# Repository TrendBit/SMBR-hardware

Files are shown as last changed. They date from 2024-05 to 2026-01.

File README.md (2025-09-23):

# SMBR - Hardware
This repository contains the documentation for all hardware modules that make up or can be connected to the Smart Modular BioReactor. All designs were made in KiCAD.

General module specification is to which modules should adhere as much as possible is in [Specification.md](Specification.md)

# General system design
All the main modules are built on a similar basis. These are the RP2040 microcontroller, CANBus and development resources (SWD, UART, etc). The individual modules, in turn, add components to this base that correspond to their specific application. For example, in the case of the Control board, this includes motor drivers or electronics that control and monitor fans. The modules communicate with each other via the CAN bus, where a custom protocol is used.

# Modules
### Interface board
Extension for RPi 4 which adds capabilities for communication and power inputs. Board serves as hub for CAN bus connection to other modules. Modules can be connected via 3 IDC cables or stacking connector on top. Board is connected to RPi via 40 pin connector. Via this connector is Rpi power and communicate with CAN bus transceiver via SPI. I2C can be used to read on board ADC which read board input voltage, current. This board also supplies 5V rail for Rpi and rest of the system. PoE module can be mounted to the board and PoE lines will be passed from RPi header.

<p align="center">
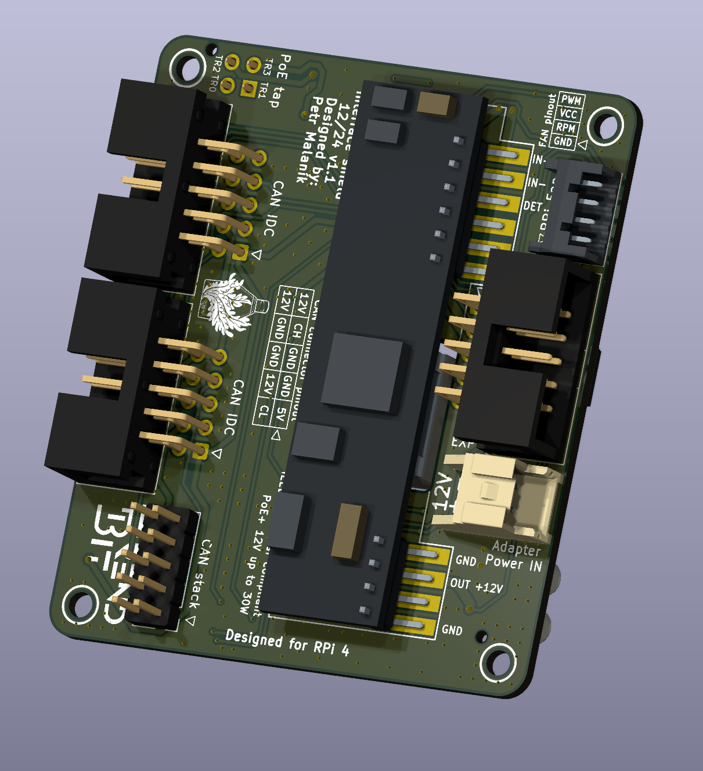
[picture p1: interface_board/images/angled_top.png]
3D Top Angled
  
&nbsp; &nbsp; &nbsp; &nbsp;
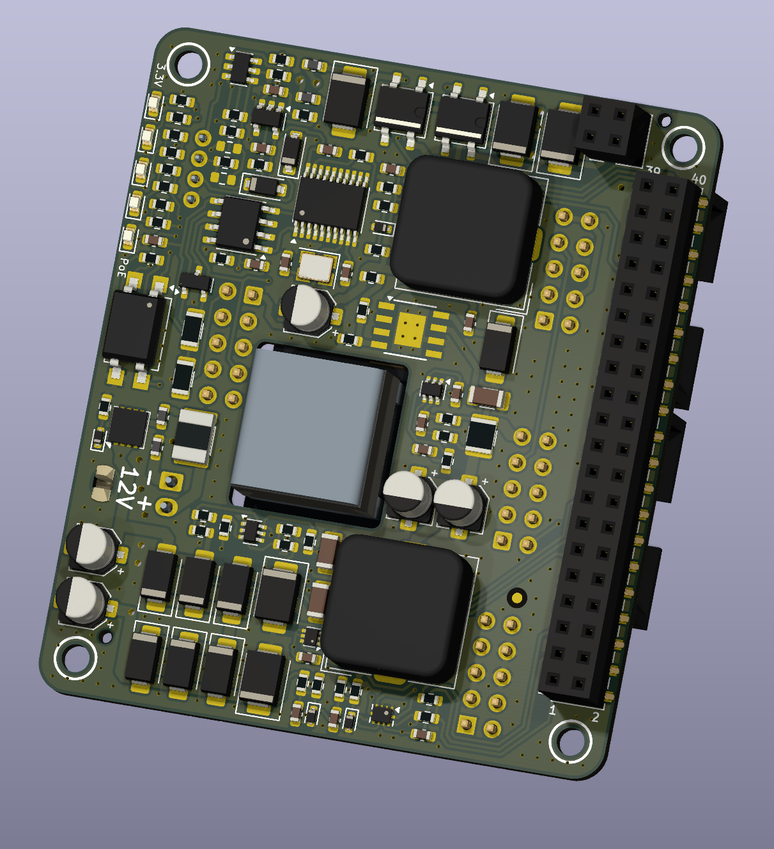
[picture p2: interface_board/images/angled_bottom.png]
3D Bottom Angled
  
</p>

# Control board
Board responsible for main control function of SMPBR. Can be used to control illumination intensity. Drives peltier element which influence temperature of algae in bottle. Controls Aerator, Peristaltic pump, Mixer and heat control fans on device. Reads temperature of heater plate and LED panel. Can be used as additional CAN bus HUB. Is designed to be stacked on top of Interface module, as third layer of sandwich RPi-Interface-Control.

<p align="center">
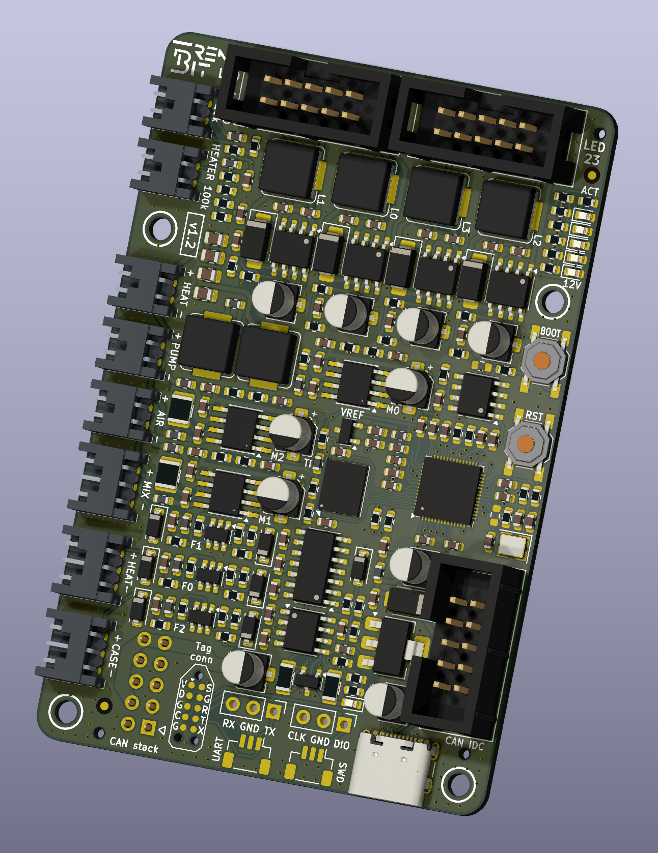
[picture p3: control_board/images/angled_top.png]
3D Top Angled
  
&nbsp; &nbsp; &nbsp; &nbsp;
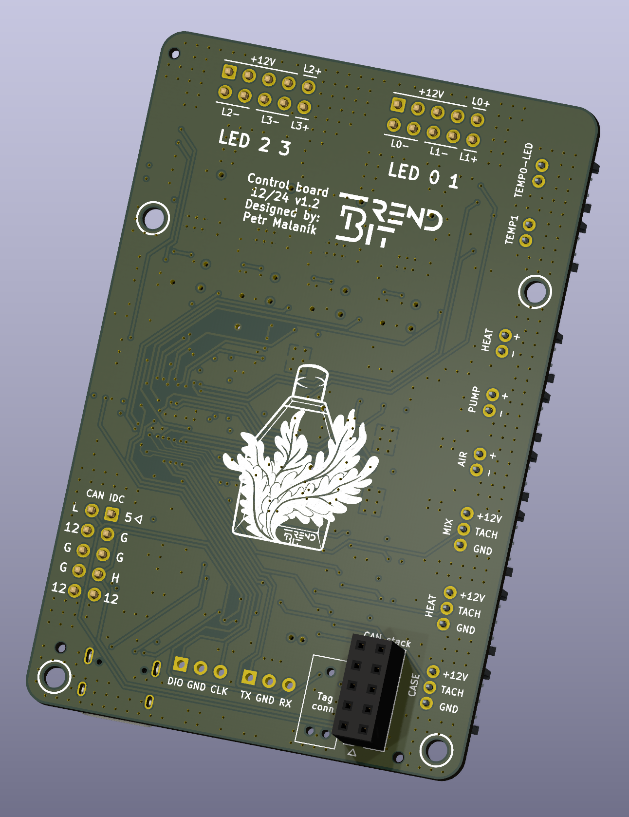
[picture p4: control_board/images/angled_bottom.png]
3D Bottom Angled
  
</p>

### Sensor board
Module performing most of the basic measurements related to experiment. Consists of three boards which  can be connected together around sampling cuvette. Sample is pumped into cuvette and after adaptation the measurements can start. For OJIP measurement sample is saturated with high power 10W Green LED and resulting value is measured with adaptive gain IR energy sensor. Another measurement is optical density which can be measured at 6 defined wavelengths. Board also measures temperature in bottle via two contact-less thermometers (thermopiles).

<p align="center">
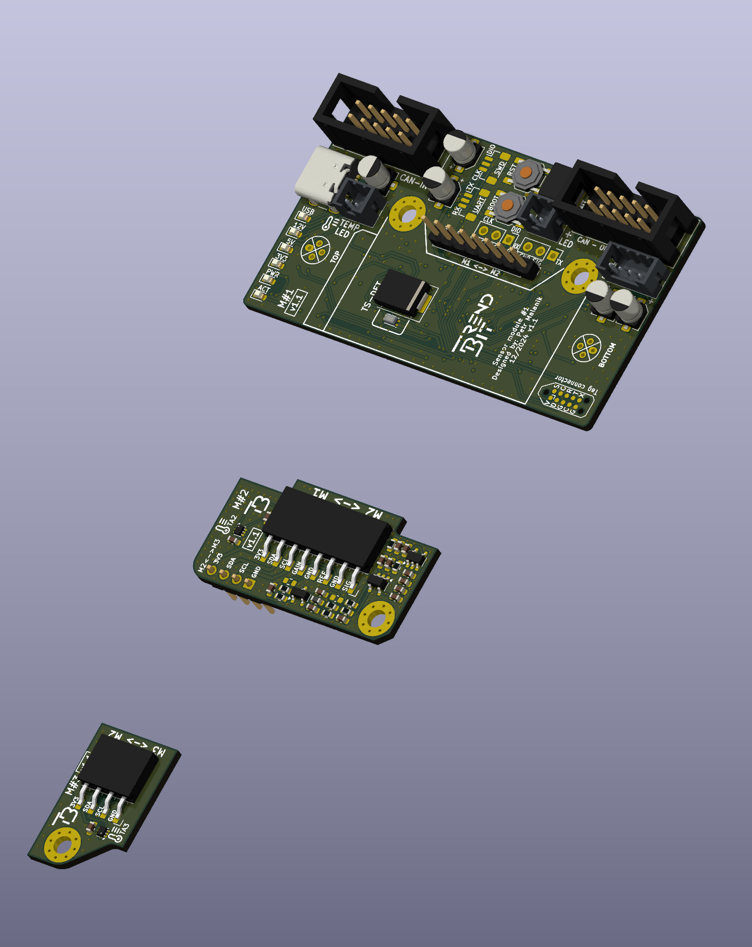
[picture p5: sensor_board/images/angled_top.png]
3D Top Angled
  
&nbsp; &nbsp; &nbsp; &nbsp;
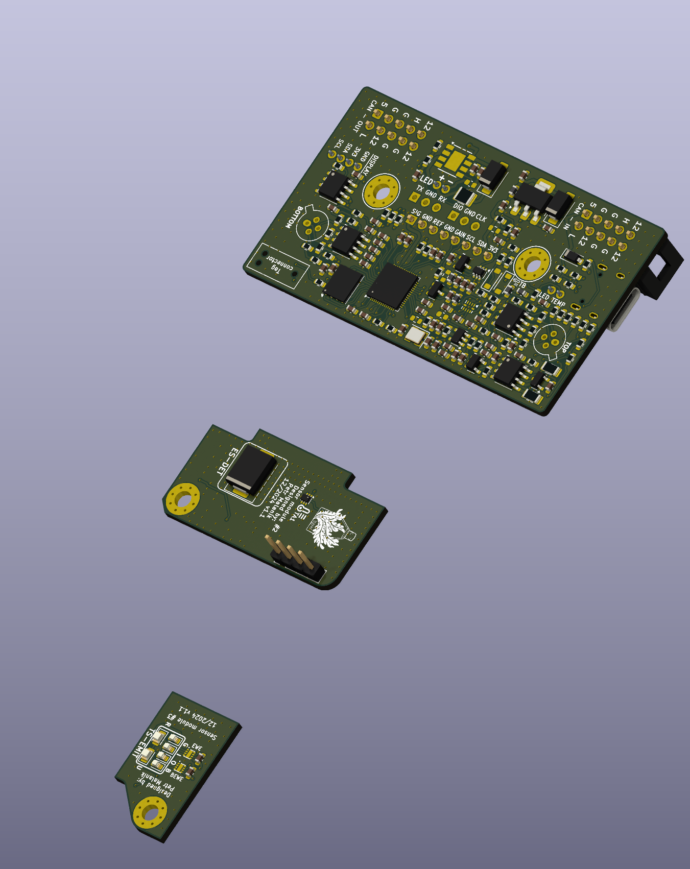
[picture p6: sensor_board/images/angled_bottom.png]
3D Bottom Angled
  
</p>

### Illumination board - Basic RGBW
SMPBR illumination panel with 4 channels. Channels can be controlled individually from control module. Each module has own power limit based on on board sense resistor. Board has integrated thermistor in order to limit heat dissipation which could influence the experiment.

This board has four basic colors:
- Red 625nm 4.8W
- Green 520nm 5.8W
- Blue 465nm 5.8W
- White (Warm) 2700K 6.1W

<p align="center">
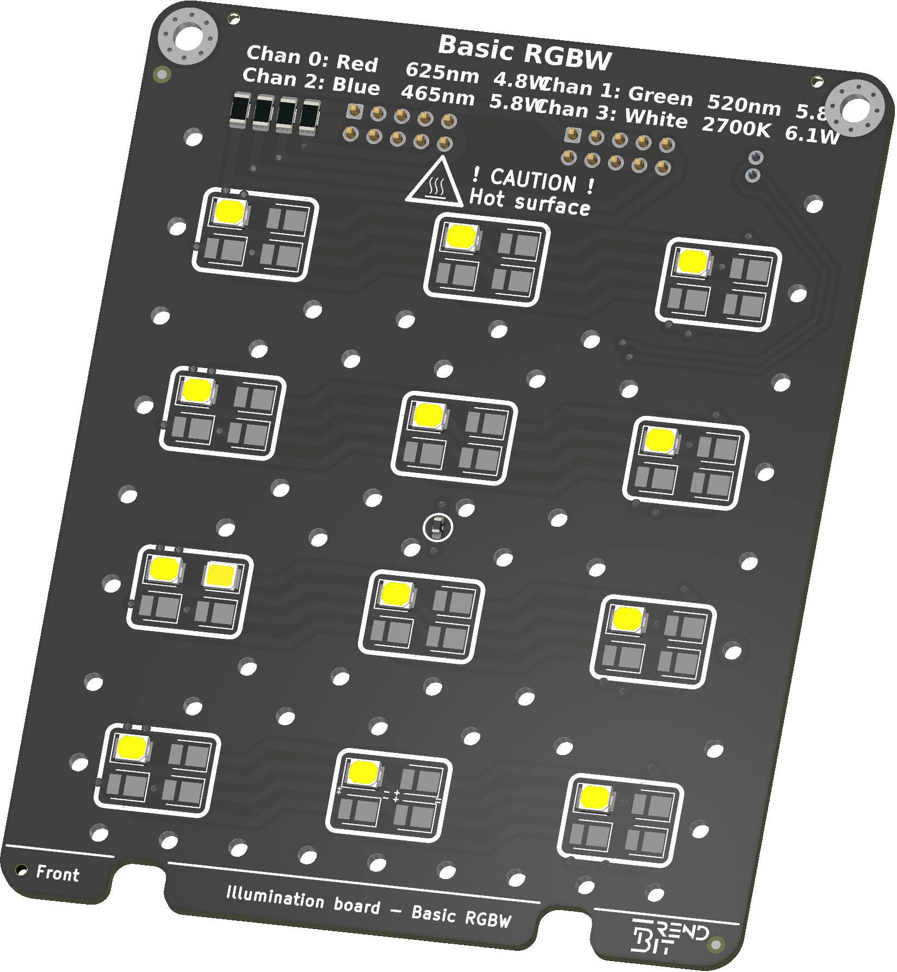
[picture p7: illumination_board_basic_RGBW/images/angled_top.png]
3D Top Angled
  
&nbsp; &nbsp; &nbsp; &nbsp;
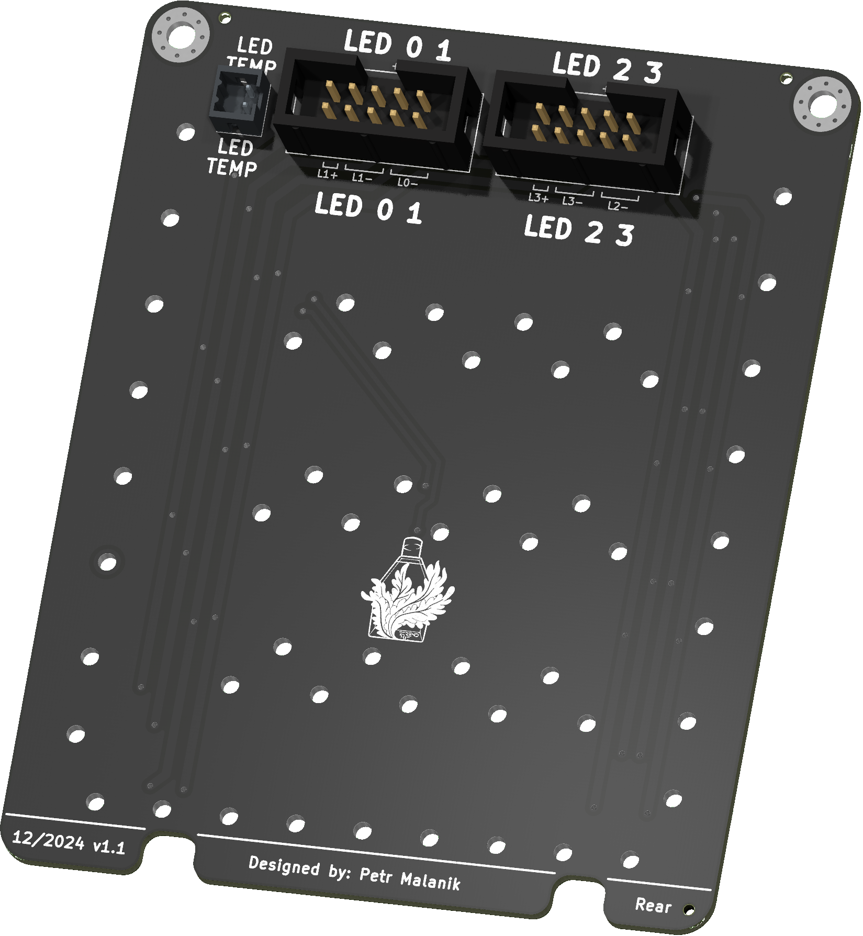
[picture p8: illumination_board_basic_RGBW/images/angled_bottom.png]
3D Bottom Angled
  
</p>

### Motor filter shield for peristaltic pump
Small PCB directly soldered to motor terminals of Peristaltic pump motor. It acts as a low pass filter reducing EMI. However, it can also be soldered directly to the motor chassis, further improving EMC. It simplifies motor connection by allowing the motor to be connected via a connector on the board.
<p align="center">
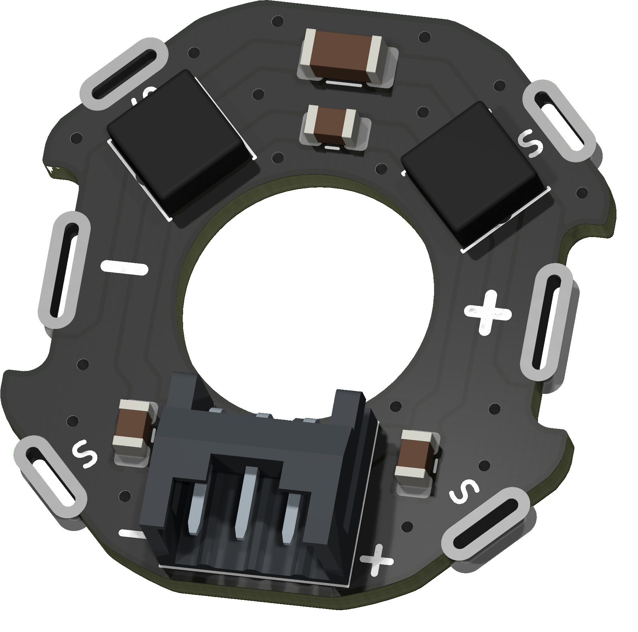
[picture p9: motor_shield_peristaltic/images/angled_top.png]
3D Top Angled
  
&nbsp; &nbsp; &nbsp; &nbsp;
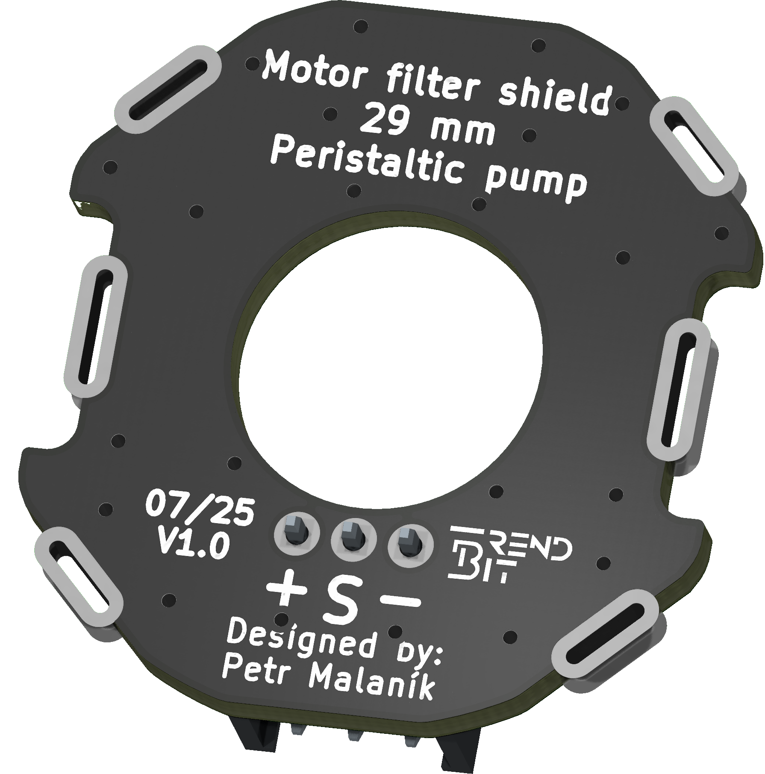
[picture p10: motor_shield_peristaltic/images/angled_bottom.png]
3D Bottom Angled
  
</p>

### Motor filter shield for air pump
Small PCB directly soldered to motor terminals of air pump motor. It acts as a low pass filter reducing EMI. However, it can also be soldered directly to the motor chassis, further improving EMC. It simplifies motor connection by allowing the motor to be connected via a connector on the board.
<p align="center">
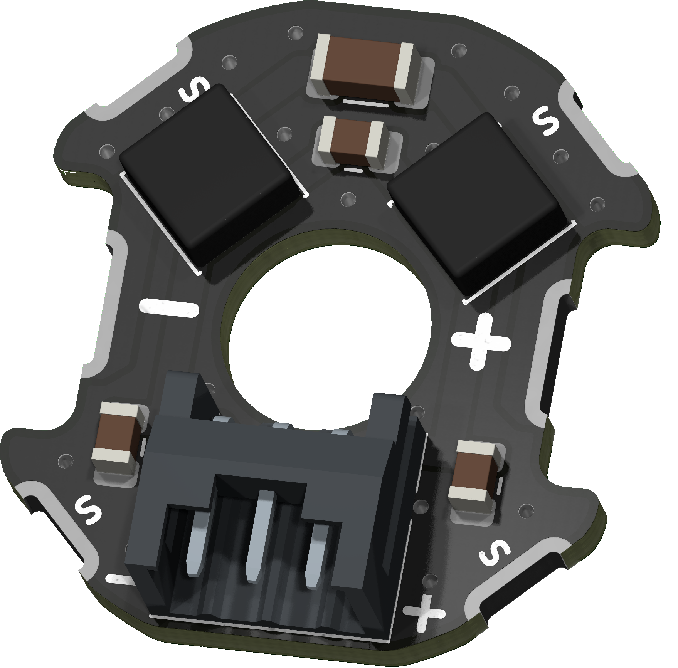
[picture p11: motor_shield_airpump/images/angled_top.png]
3D Top Angled
  
&nbsp; &nbsp; &nbsp; &nbsp;
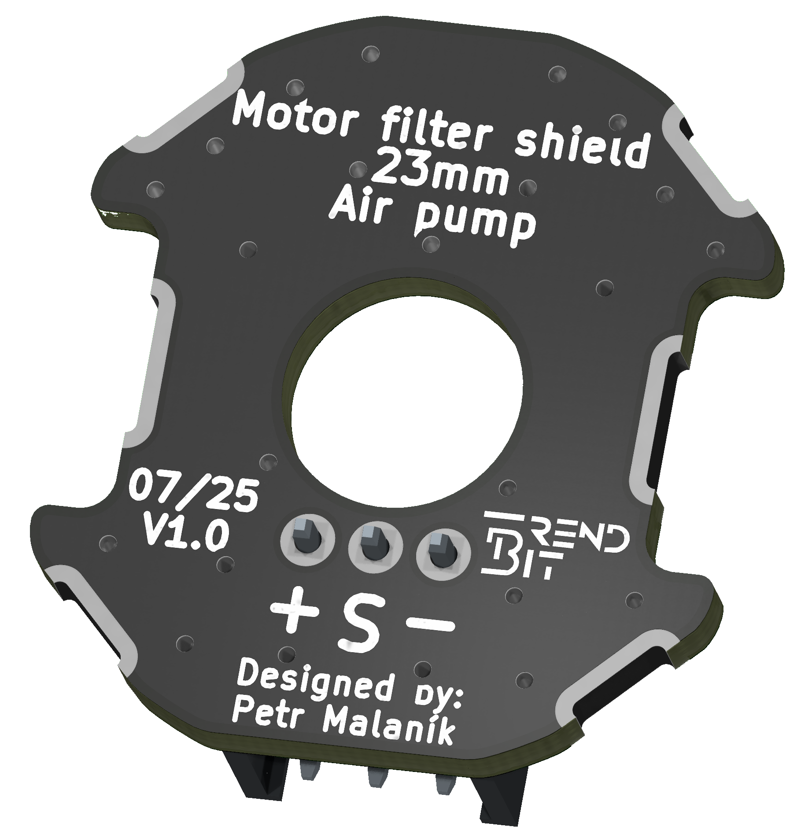
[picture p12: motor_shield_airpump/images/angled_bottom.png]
3D Bottom Angled
  
</p>

### [WIP] Pump board 
Board for expansion pump module, which is used to control additional peristaltic pumps. To this board up to 4 peristaltic pumps can be connected a controlled. Module can be connected to SMPBR reactor via expansion port. Multiple of those modules can be connected to one bio-reactor and can be chained bia expansion ports. Module also have external power, because when more modules will be connected to expansion port, main adapter can be overloaded. External power input is prioritized over power from extension cable.
<p align="center">
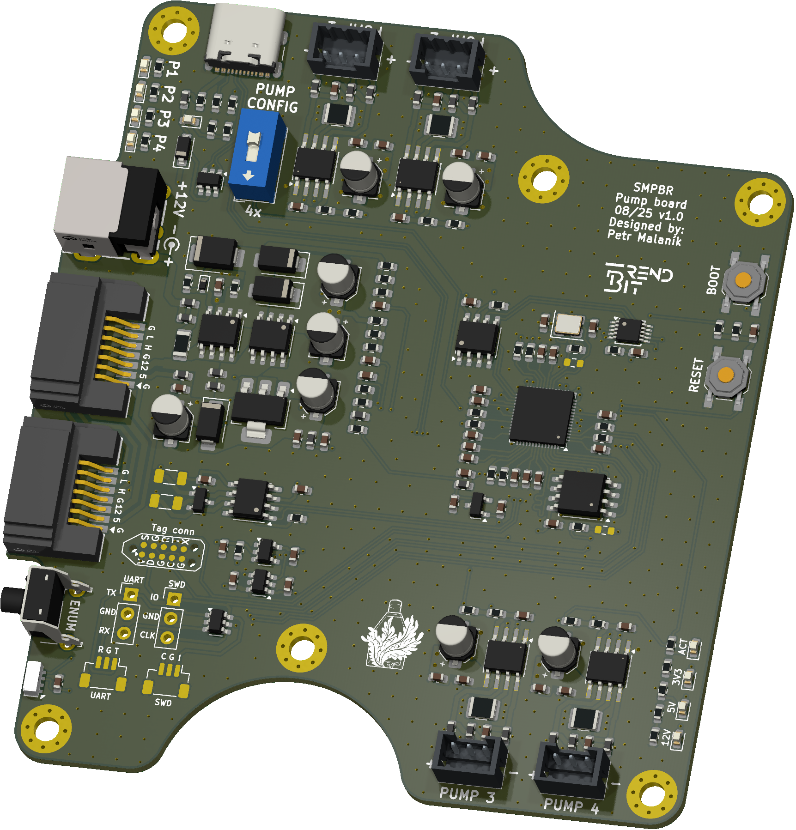
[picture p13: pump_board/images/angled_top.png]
3D Top Angled
  
&nbsp; &nbsp; &nbsp; &nbsp;
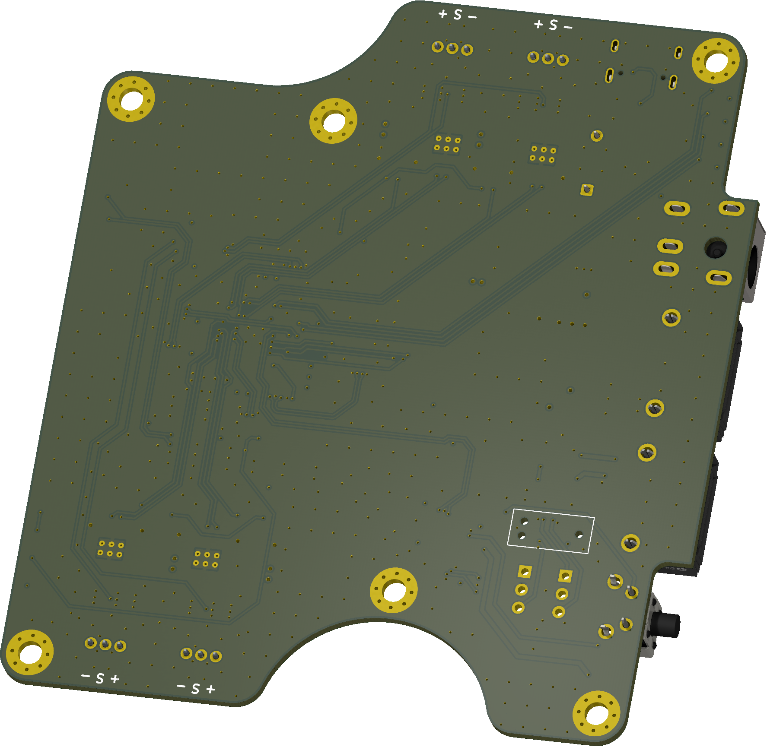
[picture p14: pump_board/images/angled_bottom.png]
3D Bottom Angled
  
</p>

### Sata Expansion port

### Fluorometer LED

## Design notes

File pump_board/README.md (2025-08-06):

# Pump board
Board for expansion pump module, which is used to control additional peristaltic pumps. To this board up to 4 peristaltic pumps can be connected a controlled. Module can be connected to SMPBR reactor via expansion port. Multiple of those modules can be connected to one bio-reactor and can be chained bia expansion ports. Module also have external power, because when more modules will be connected to expansion port, main adapter can be overloaded. External power input is prioritized over power from extension cable.

<p align="center">
  3D Top Angled
&nbsp; &nbsp; &nbsp; &nbsp;
  3D Bottom Angled
</p>

## Manufacturing configuration
- Single pieces
- Thickness: 1.6mm
- Layers: 4
- Color: Green/White
- Surface: HASL Lead Free
- Confirm Production file: No
- Mark: Remove
- Assembly: Standard - Top Side
- Edge Rails/Fiducials: Added by JLCPCB
- Confirm parts placement: Yes

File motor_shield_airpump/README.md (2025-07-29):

### Motor filter shield for air pump
Small PCB directly soldered to motor terminals of air pump motor. It acts as a low pass filter reducing EMI. However, it can also be soldered directly to the motor chassis, further improving EMC. It simplifies motor connection by allowing the motor to be connected via a connector on the board.

<p align="center">
  3D Top Angled
&nbsp; &nbsp; &nbsp; &nbsp;
  3D Bottom Angled
</p>

## Manufacturing configuration
- Panel by customer, 3x3
- Thickness: 1.6mm
- Color: Black/White
- Surface: HASL Lead Free
- Confirm Production file: Yes
- Mark: Remove
- Assembly: Standard - Both sides
- Castelated holes: Yes (2 sides)
- Assembly: Standard - Top Side
- Edge Rails/Fiducials: Added by customer
- Confirm parts placement: Yes

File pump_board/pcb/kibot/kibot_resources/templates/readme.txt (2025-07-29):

<p align="center" width="100%">
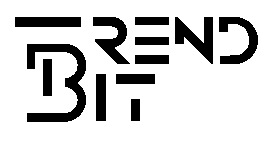
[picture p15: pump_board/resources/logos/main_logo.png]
  
</p>

<h1 align="center">${PROJECT_NAME} / ${BOARD_NAME}</h1>

<p align="center">
  3D Top Angled
&nbsp; &nbsp; &nbsp; &nbsp;
  3D Bottom Angled
</p>

***

## SPECIFICATIONS

| Parameter | Value | 
| --- | --- |
| Dimensions | ${bb_w_mm} × ${bb_h_mm} mm |

***

## DIRECTORY STRUCTURE

    .
    ├─ Computations       # Misc calculations
    ├─ HTML               # HTML files for generated webpage
    ├─ Images             # Pictures and renders
    │
    ├─ kibot_resources    # External resources for KiBot
    │  ├─ colors          # Color theme for KiCad
    │  ├─ fonts           # Fonts used in the project
    │  ├─ scripts         # External scripts used with KiBot
    │  └─ templates       # Templates for KiBot generated reports
    │
    ├─ kibot_yaml         # KiBot YAML config files
    ├─ KiRI               # KiRI (PCB diff viewer) files
    │
    ├─ lib                # KiCad footprint and symbol libraries
    │  ├─ 3d_models       # Component 3D models
    │  ├─ lib_fp          # Footprint libraries
    │  └─ lib_sym         # Symbol libraries
    │
    ├─ Logos              # Logos
    │
    ├─ Manufacturing      # Assembly and fabrication documents
    │  ├─ Assembly        # Assembly documents (BoM, pos, notes)
    │  │
    │  └─ Fabrication     # Fabrication documents (ZIP, notes)
    │     ├─ Drill Tables # CSV drill tables
    │     └─ Gerbers      # Gerbers
    │
    ├─ Report             # Reports for ERC/DRC
    ├─ Schematic          # PDF of schematic
    ├─ Templates          # Title block templates
    ├─ Testing
    │  └─ Testpoints      # Testpoints tables      
    │
    └─ Variants           # Outputs for assembly variants

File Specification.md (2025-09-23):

# General specification for SMBR modules
This specification describes the characteristics of modules that should be adhered to under ideal conditions when developing new modules. The purpose is to ensure maximum consistency between modules and thus increase the compatibility of firmware modules and components. However, this should not be at the expense of reduced functionality or user discomfort. 

## MCU
For maximum FW compatibility (modules, components, libraries), the RP2040 microcontroller from the RaspberryPi Foundation should be used. Alternatively, if it is not suitable, then the RP2354 or other future models can be used, provided they are compatible with the FW base. The advantage of using the same MCU is, for example, that identical code can be used for CAN bus content, message routing, and administrative message processing, regardless of which module it is located on. The standard MCU speed is 200 MHz with a 12 MHz crystal.

#### CAN Bus
The bus interface is ideally connected to the GPIO_4(TX) and GPIO_5(RX) pins of the MCU. The converter is capable of reaching speeds of 1 Mbit/s (e.g., SN65HVD230 in HighSpeed mode), but the actual speed used is 500 kB/s. Overvoltage protection on bus lines. Termination should be on the furthest module, but due to potentially strong interference, it is primarily expected on the Sensor module. If termination is installed on other modules by default, it should be disconnectable using a switch/jumper/pin header. The second termination is permanently installed on the Interface module.

#### Flash Memory
Externally connected QSPI Flash memory for the MCU program. It should not be used for storing persistent data (calibration) but for the program (main and bootloader). Minimum size 16 MBit(MB). To store application data, the module should contain some additional memory, such as I2C EEPROM. 

EEPROM is used as standard memory and connected to I2C1 on pins GPIO18/19 with address 0x50 (7-bit). It is used to store information about the module and its instance.

## Interfaces
Standard interfaces used for communication with the board. CAN bus is the only application interface; the others are used for development and debugging.

#### USB-Type C
Port enabling data transfer via USB FS with UBS Type-C connector. It is connected to the MCU's USB_Dx pins. It must contain CC pull-down resistors (2x 5.1k) and should enable power supply to the device via USB so that the module's firmware can be updated.

It allows you to upload a CAN bootloader (catapult) or standard application firmware for testing using a USB bootloader. It can also be used to connect to the module's CLI interface, which contains information about when the system was built and can provide additional development tools.

#### UART + SWD
Development interface enabling FW stepping with the help of a connected debug probe. The use of an RPi Debug probe is primarily assumed, which corresponds to the pinout of the connectors. The FW logger output is connected to the serial port, but the logger must be enabled in the FW configuration and set to a sufficient level. The serial port speed is 921600 baud.

#### CAN connector
Connector for CAN BUS application interface. It can exist in multiple form factors, but two are most common are 10-pin IDC connector for internal connections within the device and external SATA connector (7-pin).

#### Tag connector
The tag connector is an alternative programming connector that allows you to work with the board when connected via pogo pins (available as a special counterpart). It contains SWD and a serial link. Its primary use is for quick connection to the board for the purpose of changing the firmware.

#### Version resistors
A divider consisting of two resistors that defines the HW version of its output voltage. The resistor values for each version should be identical between modules. The divider is connected to the ADC0 input of the RP2040 MCU.

Values (1% precision):
| Version | R_V1 | R_V2 | Voltage |
|---|---|---|---|
| X.0 |  1k  |  10k |  3.00 V |
| X.1 |  10k |  1k  |  0.30 V |
| X.2 |  10k | 5.1k |  1.11 V |
| X.3 | 5.1k |  10k |  2.18 V |
| X.4 | 5.1k |  1k  |  0.54 V |
| X.5 |  1k  | 5.1k |  2.76 V |

Reserved values:
0V, 3.3V, 1.65V

#### Buttons
Buttons for basic control of the board. These are the reset and boot buttons. The reset button is connected to the MCU RUN pin. Pressing it resets the MCU, pressing it twice in quick succession starts the built-in CAN bootloader and pauses the boot process so that the FW can be uploaded via CAN. However, the CAN bootloader must already be uploaded to the system in some way (it can also be together with the application FW). Holding down the BOOT button during startup or reset activates the USB bootloader, allowing you to upload the CAN bootloader, application firmware, or both. The BOOT button is connected to the CS pin of the Flash memory.

#### LEDs
Each module should contain at least one primary diagnostic LED (LED1) indicating the status of the device. This LED should be visible to the user without major modifications to the device. The preferred color of this signal LED is green, and it should be on pin GPIO24 of the RP2040 MCU. This LED is configurable for each module, so it can be set using FW. However, it is also used by the bootloader (Katapult) and should therefore be on the same pin on all devices, as this allows the same bootloader firmware to be used on all boards. The function of this LED is defined by an abstract class from which all modules are derived, and its behavior is therefore the same for all modules. During bootloader operation, it flashes slowly (1 Hz) and indicates the firmware flashing process. During application operation, it flashes quickly (2.5 Hz) and stops flashing in the event of a critical error.

It is recommended to connect the secondary LED (LED2) to GPIO25 MCU, and it should be yellow. The function of this LED is not defined, but it should indicate ongoing processes related to a specific function of the model (for example, OJIP measurement on the sensor module).

Additional red LEDs should ideally indicate active power branches. This can be used to detect power supply problems, for example, in external modules that may be powered by a hybrid power supply.

#### Enumeration interface
Button and indicator LED designed for modules that allow multiple instances in the system, such as the pump module. Pressing the button sets the instance, which is then indicated by the color of the LED. The button is normally connected to GPIO22. An RGB LED is used as the LED and can be controlled arbitrarily, but it is recommended to use a single-pin addressing protocol (such as WS2818) on GPIO23.

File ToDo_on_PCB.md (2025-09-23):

# Pump board v 1.1
- [ ] Fix incorrect type of Barrel jack connector

# Fluoro LED board v1.3
- [ ] Change PCB from aluminum backed to normal FR4 with heat vias
    - In this case connectors can be used
- [ ] Use one 4-pin connector for  to reduce number of wires

# Sensor board v1.2
- [ ] Add protection resistors to SWD connector (100R) based on pico-probe
- [ ] Connect Fluorometer LED with 3 or 4 wire cable

# Control board v1.3
- [ ] Add protection resistors to SWD connector (100R) based on pico-probe
- [ ] Reduce input current limitation on FAN control MOSFETs
    - Those resistors limits how fast can FAN MOSFET close and open
- [ ] Mark CAN bus resistors as DNP (those should be placed on Sensor module)
    - Or make them possible to enable by resistor

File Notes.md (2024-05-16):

# RPI - Can bus  

 - Add overlay to load during boot to `/boot/firmware/config.txt`  
```  
dtparam=spi=on  
dtoverlay=mcp2515-can0,oscillator=12000000,interrupt=25,spimaxfrequency=2000000  
```  
- Install tool: `sudo apt-get install can-utils`  
- Setup interface: `sudo ip link set can0 up type can bitrate 1000000`  
- Persistently configure interface in file `/etc/network/interfaces`
```
auto can0
iface can0 can static
        bitrate 1000000
```

## Test  
CAN interface can be setup in loopback mode.  
```  
sudo ip link set can0 down  
sudo ip link set can0 type can bitrate 1000000 loopback on  
sudo ip link set can0 up type can bitrate 1000000  
```  
In two terminals run this commands:  
Term #1 - `candump can0`  
Term #2 - `cansend can0  000#11.22.33.44`  

Result should be two lines (one for send, one for receive via loopback):
```
  can0  000   [4]  11 22 33 44
  can0  000   [4]  11 22 33 44
```
If interface is not setup as loopback no data will be visible in `candump` because frame was not ACKed.

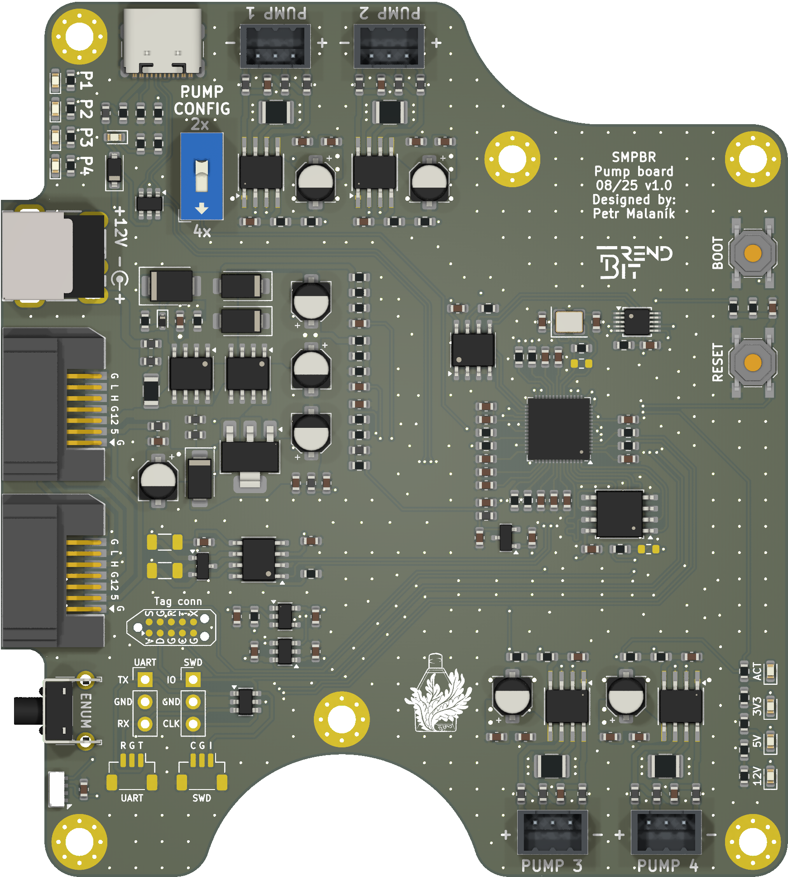
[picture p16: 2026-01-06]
pump_board/images/top.png

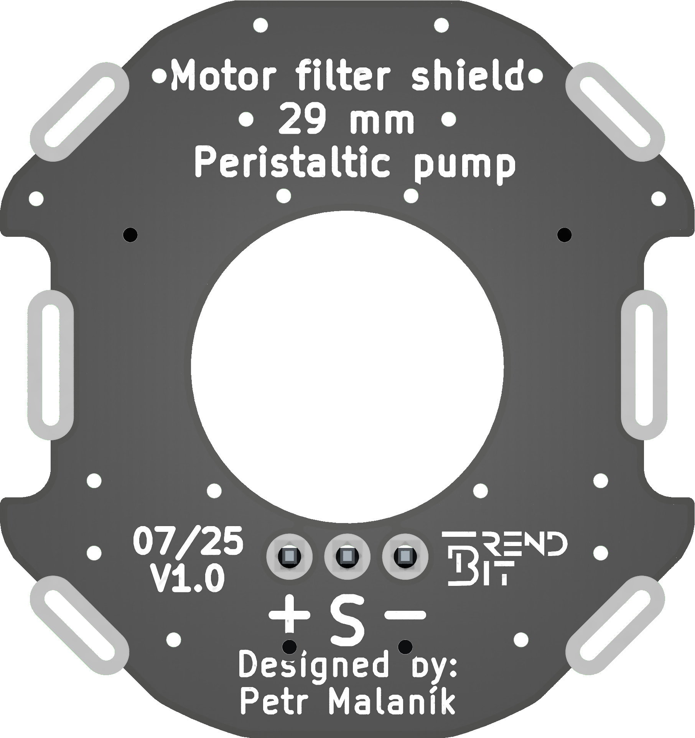
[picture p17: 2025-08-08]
motor_shield_peristaltic/images/bottom.png

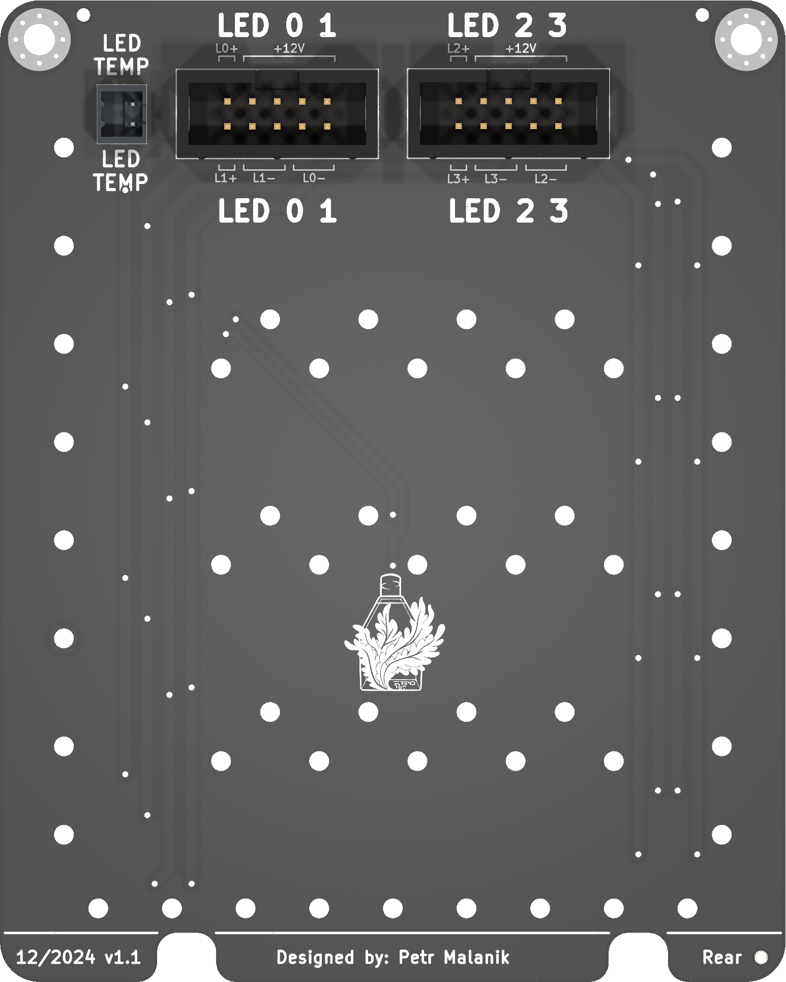
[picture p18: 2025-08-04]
illumination_board_basic_RGBW/images/bottom.png

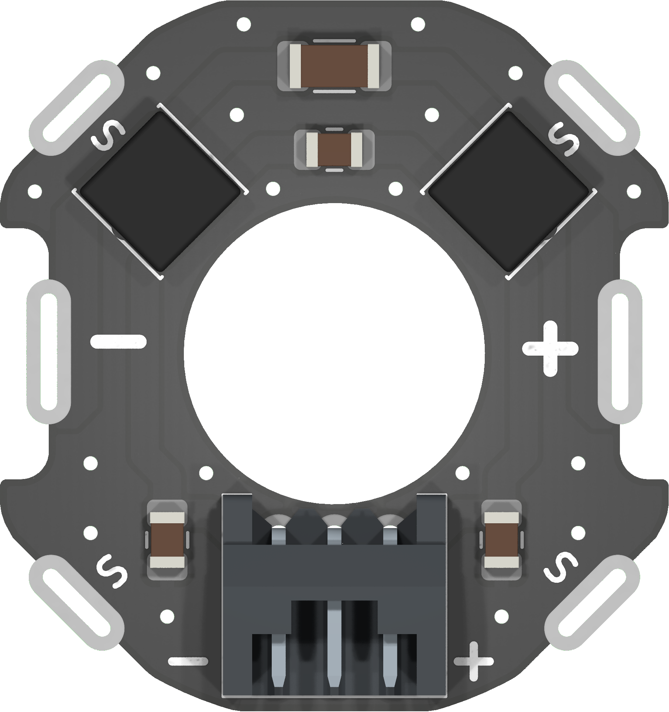
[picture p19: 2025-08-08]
motor_shield_peristaltic/images/top.png

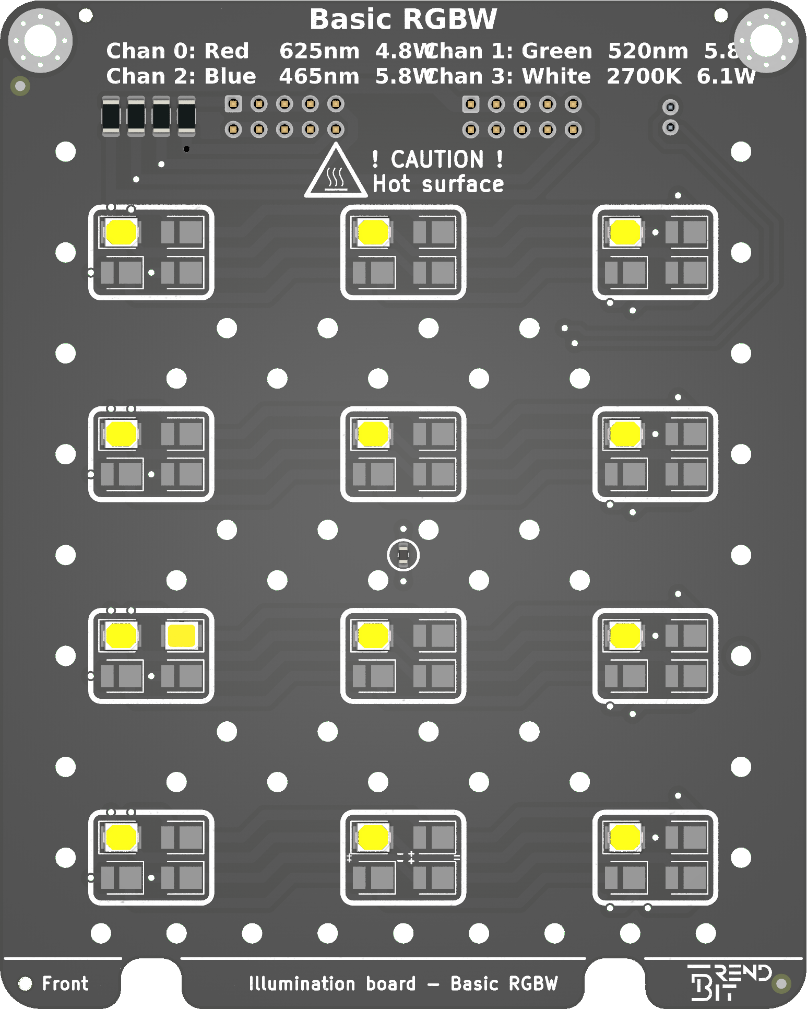
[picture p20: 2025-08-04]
illumination_board_basic_RGBW/images/top.png

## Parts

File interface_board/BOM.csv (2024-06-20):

Reference | Value | Package | Quantity | MPN | LCSC
C2,C4,C10,C11,C15 | 10nF | Capacitor_SMD:C_0603_1608Metric | 5 |  | C57112
C8,C9 | 10pF | Capacitor_SMD:C_0603_1608Metric | 2 |  | C1634
C12,C13,C14,C18,C19,C23 | 100nF | Capacitor_SMD:C_0603_1608Metric | 6 |  | C14663
C5,C6,C16 | 10uF/50V | Capacitor_SMD:C_1206_3216Metric | 3 |  | C13585
C1,C3,C7,C17,C20,C21,C22 | 10uF/25V | Capacitor_SMD:CP_Elec_4x5.4 | 7 | CK1E100M-CRC54 | C3001226
J4,J5,J6 | HC-JN254-2-05-W | Connector_IDC:IDC-Header_2x05_P2.54mm_Horizontal | 3 | HC-JN254-2-05-W | C5372873
J2 | PH-00244 | Connector_PinHeader_2.54mm:PinHeader_2x05_P2.54mm_Vertical | 1 | PH-00244 | C2829881
J3 | FH-00221 | Connector_PinSocket_2.54mm:PinSocket_2x02_P2.54mm_Vertical | 1 | FH-00221 | C2685206
P1 | PM254-2-20-S-8.5 | Connector_PinSocket_2.54mm:PinSocket_2x20_P2.54mm_Vertical_SMD | 1 | PM254-2-20-S-8.5 | C3975165
Y2 | 12MHz | Crystal:Crystal_SMD_Abracon_ABM8G-4Pin_3.2x2.5mm | 1 | ABM8G-12.000MHZ-4Y-T3 | C2933034
D12,D13,D14,D15,D20,D21 | CDBA340 | Diode_SMD:D_SMA | 6 | CDBA340-HF | C8678
D1,D2,D5 | SMBJ58CA | Diode_SMD:D_SMB | 3 | SMBJ58CA | C19077592
D6,D9 | SMBJ13CA | Diode_SMD:D_SMB | 2 | SMBJ13CA | C19077568
D7,D10,D22 | MM5Z5V1 | Diode_SMD:D_SOD-523 | 3 | MM5Z5V1 | C2904385
D8 | BZT52C8V2 | Diode_SMD:D_SOD-523 | 1 | BZT52C8V2 | C19077465
D3,D4 | ABS20M | Diode_SMD:Diode_Bridge_Diotec_ABS | 2 | MB24S | C2903933
F1 | 3A | Fuse:Fuse_1812_4532Metric | 1 | 1812L300/24SLER | C5301865
FB1,FB2,FB3,FB4 | 10R@100MHz | Inductor_SMD:L_0603_1608Metric | 4 | GZ1608D601TF | C2971881
L1,L2 | 22uH/3A | Inductor_SMD:L_TDK_SLF12565 | 2 | FHC1365-220M | C2761928
D11,D16,D17,D18,D19 | RED | LED_SMD:LED_0603_1608Metric | 5 | KT-0603R | C2286
U4 | TLA2024 | Package_DFN_QFN:Texas_UQFN-10_1.5x2mm_P0.5mm | 1 | TLA2024IRUGT | C2876104
U7 | INA213 | Package_DFN_QFN:UQFN-10_1.4x1.8mm_P0.4mm | 1 | INA213AIRSWR | C2870401
U5 | SN65HVD230 | Package_SO:SOIC-8_3.9x4.9mm_P1.27mm | 1 | SN65HVD230DR | C12084
U2 | FOD817S | Package_SO:SSO-4_6.7x5.1mm_P2.54mm_Clearance8mm | 1 | FOD817S | C106900
U6 | TPS5430DDA | Package_SO:TI_SO-PowerPAD-8_ThermalVias | 1 | TPS5430DDAR | C9864
U3 | MCP2515-I/ST | Package_SO:TSSOP-20_4.4x6.5mm_P0.65mm | 1 | MCP2515-I/ST | C185941
Q2,Q3 | SiSA35DN | Package_SO:Vishay_PowerPAK_1212-8_Single | 2 | SISA35DN-T1-GE3 | C177036
D23 | PSM712-LF-T7 | Package_TO_SOT_SMD:SOT-23 | 1 | PSM712-LF-T7 | C32677
Q1,Q4 | DMN63D8LDW | Package_TO_SOT_SMD:SOT-363_SC-70-6 | 2 | DMN63D8LDW-7 | C211422
R1,R3,R5,R6,R9,R11,R12,R13,R15,R19,R24,R30,R31,R32,R36,R38,R42 | 10k | Resistor_SMD:R_0603_1608Metric | 17 |  | C25804
R2,R7,R8,R17 | 100k | Resistor_SMD:R_0603_1608Metric | 4 |  | C25803
R4,R10,R27,R28,R37,R41 | 10R | Resistor_SMD:R_0603_1608Metric | 6 |  | C23193
R18,R23,R25,R29,R43 | 4.7k | Resistor_SMD:R_0603_1608Metric | 5 |  | C23162
R20,R21,R22,R33 | 680R | Resistor_SMD:R_0603_1608Metric | 4 |  | C23228
R34,R40 | 0R | Resistor_SMD:R_0603_1608Metric | 2 |  | C21189
R14,R16 | 60R | Resistor_SMD:R_1206_3216Metric | 2 |  | C23204
R26 | 10mR/0.5W | Resistor_SMD:R_1210_3225Metric | 1 |  | C270845
J7 | DF3A-04P | TCY_connectors:Hirose_DF3A-04P-2DS_1x04_P2.00mm_Horizontal | 1 | DF3A-4P-2DS
J1 | 1744426-2 | TCY_connectors:TE_EP2.5_1744426-2_1x02_P2.50mm_Horizontal | 1 | 1744426-2 | C5169683
U1 | AG5300 | TCY_modules:Silvertel-AG5300_Horizontal | 1 | AG5300

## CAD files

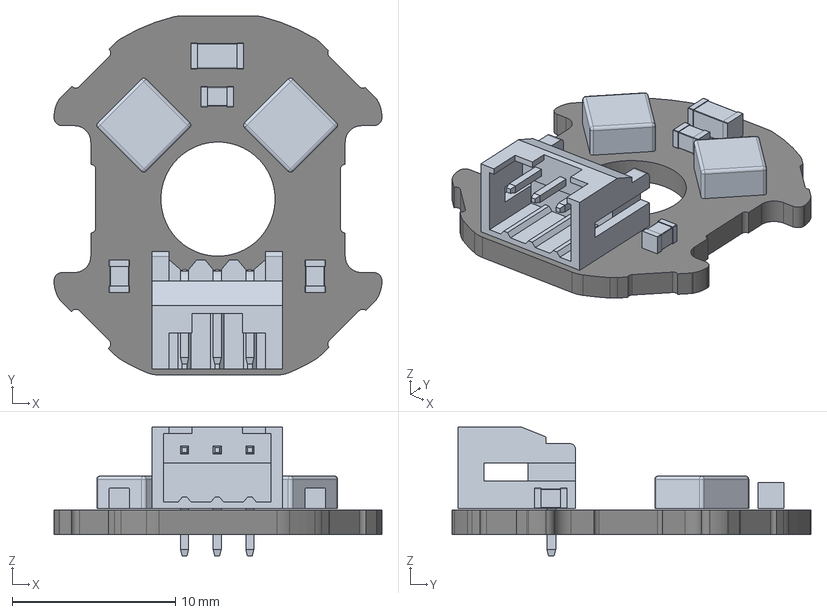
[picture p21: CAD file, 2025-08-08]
motor_shield_airpump/3d/motor_shield_airpump.step
20.1 x 22.0 x 7.90 mm
C_1206_3216Metric
Hirose_DF3A-03P-2DS_1x03_P2.00mm_Horizontal
C_0805_2012Metric x 3
L_Pulse_PA4332 x 2
kibot_1gd4crks_PCB

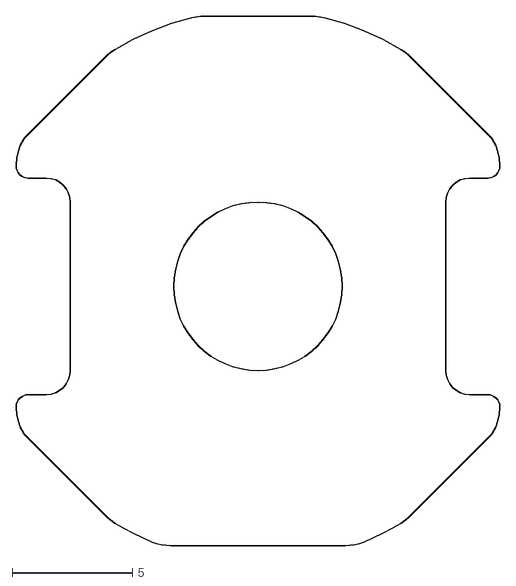
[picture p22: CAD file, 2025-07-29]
motor_shield_airpump/resources/Motor_filter_airpump.dxf
20.1 x 22.0

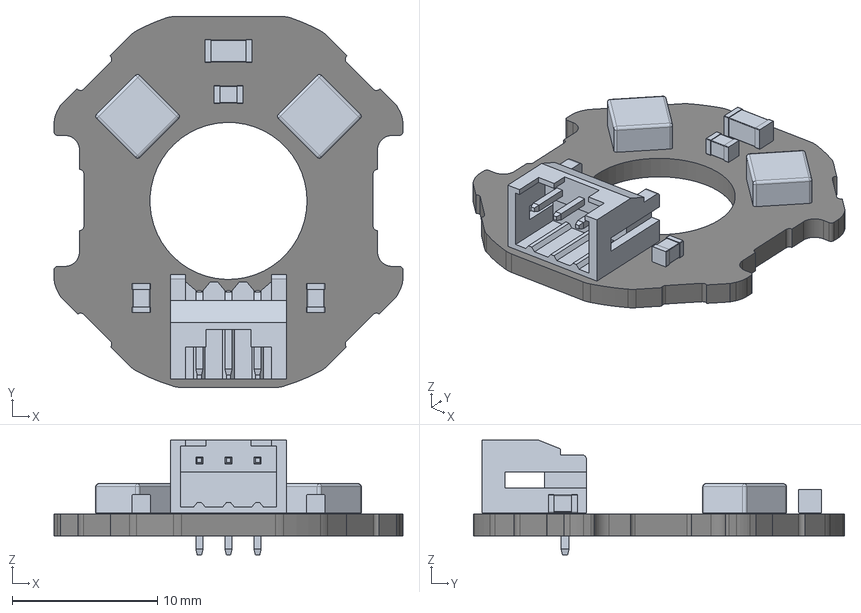
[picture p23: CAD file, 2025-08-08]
motor_shield_peristaltic/3d/motor_shield_peristaltic.step
24.0 x 25.5 x 7.90 mm
C_1206_3216Metric
L_Pulse_PA4332 x 2
Hirose_DF3A-03P-2DS_1x03_P2.00mm_Horizontal
C_0805_2012Metric x 3
kibot_nl32sm2i_PCB

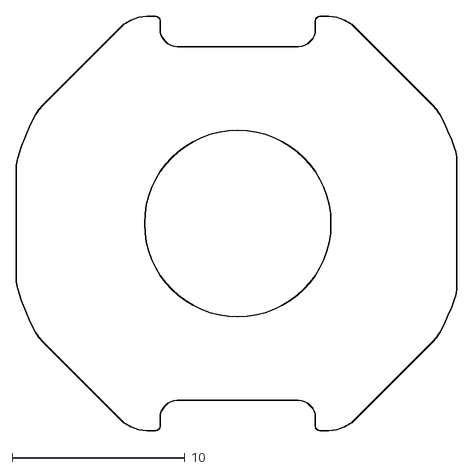
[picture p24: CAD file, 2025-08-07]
motor_shield_peristaltic/resources/PCB_Outlines.dxf
25.5 x 24.0

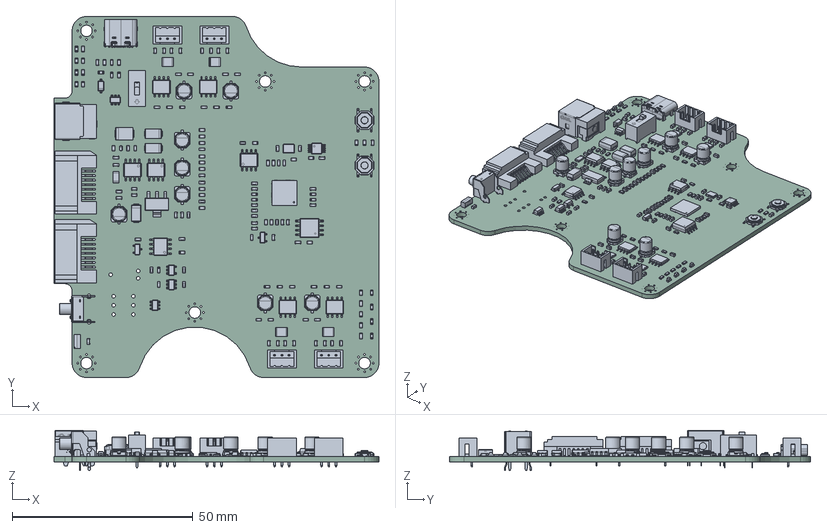
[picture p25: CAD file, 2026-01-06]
pump_board/3d/pump_board.step
90.0 x 100.0 x 11.2 mm
R_0603_1608Metric x 49
C_0603_1608Metric x 51
R_1210_3225Metric x 4
L_0603_1608Metric x 21
LED_0603_1608Metric x 9
SOIC-8_3.9x4.9mm_P1.27mm x 4
Hirose_DF3A-03P-2DSA_1x03_P2.00mm_Vertical x 4
TSSOP-10_3x3mm_P0.5mm
SW_SPST_TL3342 x 2
SOT-23-6 x 3
SW_Tactile_SPST_Angled_PTS645Vx58-2LFS
CP_Elec_4x5.4 x 8
Fuse_1206_3216Metric
Texas_HTSOP-8-1EP_3.9x4.9mm_P1.27mm_EP2.85x4.9mm_Mask2.4x3.1mm_ ThermalVias x 4
QFN-56-1EP_7x7mm_P0.4mm_EP3.2x3.2mm
D_SMB
SOT-23 x 2
HYCW02-SATA07-250B x 2
Crystal_SMD_Abracon_ABM8G-4Pin_3.2x2.5mm
WS2812B_2.0x4.0mm_Side_view
SOIC-8_5.3x5.3mm_P1.27mm
D_SOD-523
D_SOD-123
D_SMA x 3
DC-044A-A250
SOT-23-5
SOT-223
USB_C_Receptacle_GCT_USB4105-xx-A_16P_TopMnt_Horizontal
SW_DIP_SPSTx01_Slide_9.78x4.72mm_W7.62mm_P2.54mm
kibot_o7kqt40r_PCB

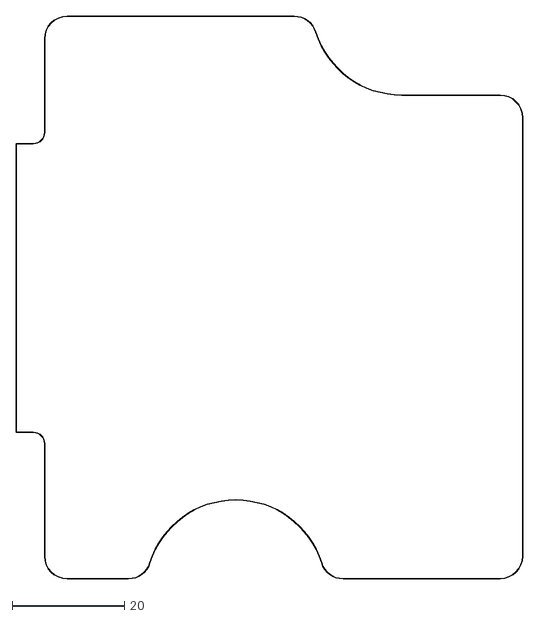
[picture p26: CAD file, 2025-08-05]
pump_board/resources/PCB_outline.dxf
90.0 x 100.0

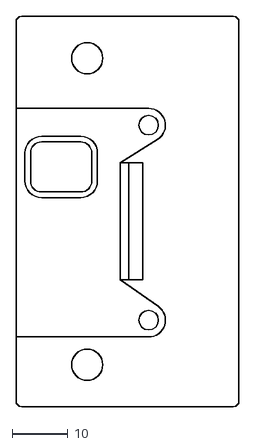
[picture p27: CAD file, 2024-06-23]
sensor_board/resources/SM_1_Mechanical.dxf
40.0 x 70.0

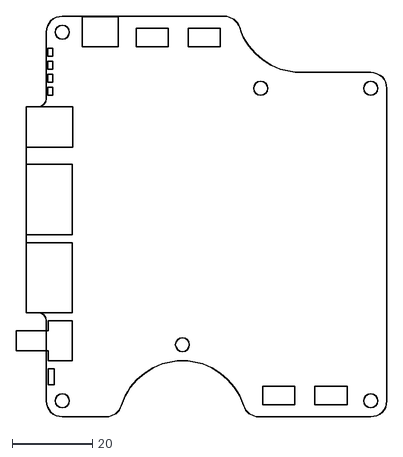
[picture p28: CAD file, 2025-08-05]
pump_board/resources/PCB_placement.dxf
92.5 x 100.0

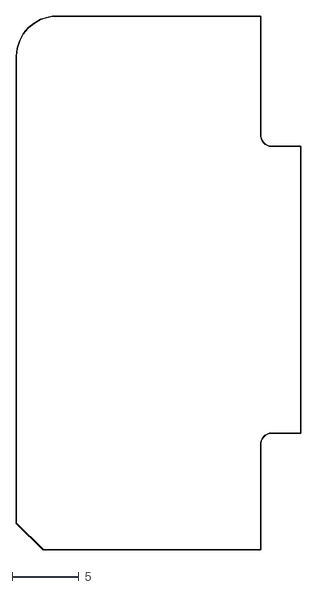
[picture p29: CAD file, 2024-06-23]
sensor_board/resources/SM_2_Edges.dxf
21.3 x 40.0

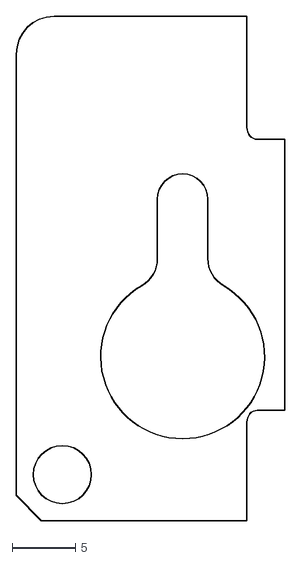
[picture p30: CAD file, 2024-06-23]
sensor_board/resources/SM_2_Mechanical.dxf
21.3 x 40.0

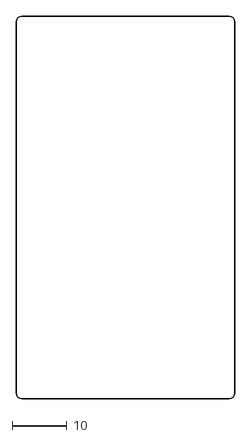
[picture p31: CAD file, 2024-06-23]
sensor_board/resources/SM_1_Edges.dxf
40.0 x 70.0

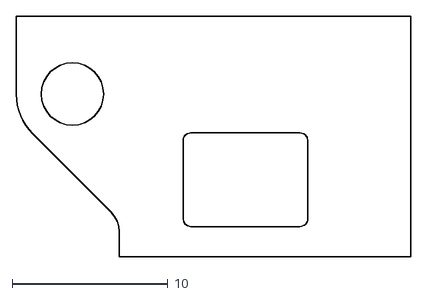
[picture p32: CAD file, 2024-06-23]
sensor_board/resources/SM_3_Mechanical.dxf
25.3 x 15.5

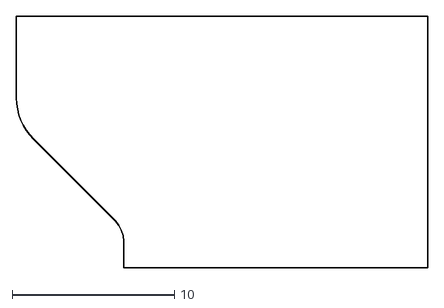
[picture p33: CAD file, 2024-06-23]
sensor_board/resources/SM_3_Edges.dxf
25.3 x 15.5

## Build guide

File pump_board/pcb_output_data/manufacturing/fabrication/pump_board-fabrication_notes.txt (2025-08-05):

FABRICATION NOTES (UNLESS OTHERWISE SPECIFIED)

1)	FABRICATE PER IPC-6012A CLASS 2.

2)	OUTLINE DEFINED IN SEPARATE GERBER FILE WITH
	"Edge_Cuts.GBR" SUFFIX.

	DIMENSIONS OF CIRCUMSIZED RECTANGLE SHOWN ON THIS
	DRAWING FOR REFERENCE ONLY.

3)	SEE SEPARATE DRILL FILES WITH ".DRL" SUFFIX 
	FOR HOLE LOCATIONS.

	SELECTED HOLE LOCATIONS SHOWN ON THIS DRAWING 
	FOR REFERENCE ONLY.

4)	SURFACE FINISH: ENIG

5)	SOLDERMASK ON BOTH SIDES OF THE BOARD SHALL 
	BE LPI, COLOR GREEN.

6)	SILK SCREEN LEGEND TO BE APPLIED PER LAYER 
	STACKUP USING WHITE NON-CONDUCTIVE EPOXY INK.

7)	ALL VIAS ARE TENTED ON BOTH SIDES UNLESS 
	SOLDERMASK OPENED IN GERBER.

8)	VENDOR SHOULD FOLLOW ROHS COMPLIANT PROCESS 
	AND Pb FREE FOR MANUFACTURING

9)	PCB MATERIAL REQUIREMENTS:

	A.	FLAMMABILITY RATING MUST MEET OR EXCEED 
		UL94V-0 REQUIREMENTS.
	B.	Tg 170 C OR EQUIVALENT.
	C.	EQUIVALENT MATERIAL SHALL BE RoHS COMPLIANT, 
		HALOGEN FREE AND APPROVED BY TRENDBIT.

10)	DESIGN GEOMETRY MINIMUM FEATURE SIZES:

	BOARD SIZE				90.000 × 100.000 mm
	BOARD THICKNESS		1.600 mm
	TRACE WIDTH			0.170 mm
	TRACE TO TRACE		-0.000 mm
	MIN. HOLE (PTH)			0.300 mm
	MIN. HOLE (NPTH)		0.650 mm
	ANNULAR RING			0.075 mm
	COPPER TO HOLE		0.150 mm
	COPPER TO EDGE		0.300 mm
	HOLE TO HOLE			0.250 mm

11)	REFER TO IMPEDANCE TABLE FOR IMPEDANCE CONTROL REQUIREMENTS.

12)	CONFIRM SPACE WIDTHS AND SPACINGS.

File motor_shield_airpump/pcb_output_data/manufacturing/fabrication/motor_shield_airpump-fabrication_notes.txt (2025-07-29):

FABRICATION NOTES (UNLESS OTHERWISE SPECIFIED)

1)	FABRICATE PER IPC-6012A CLASS 2.

2)	OUTLINE DEFINED IN SEPARATE GERBER FILE WITH
	"Edge_Cuts.GBR" SUFFIX.

	DIMENSIONS OF CIRCUMSIZED RECTANGLE SHOWN ON THIS
	DRAWING FOR REFERENCE ONLY.

3)	SEE SEPARATE DRILL FILES WITH ".DRL" SUFFIX 
	FOR HOLE LOCATIONS.

	SELECTED HOLE LOCATIONS SHOWN ON THIS DRAWING 
	FOR REFERENCE ONLY.

4)	SURFACE FINISH: HAL LEAD-FREE

5)	SOLDERMASK ON BOTH SIDES OF THE BOARD SHALL 
	BE LPI, COLOR BLACK.

6)	SILK SCREEN LEGEND TO BE APPLIED PER LAYER 
	STACKUP USING WHITE NON-CONDUCTIVE EPOXY INK.

7)	ALL VIAS ARE TENTED ON BOTH SIDES UNLESS 
	SOLDERMASK OPENED IN GERBER.

8)	VENDOR SHOULD FOLLOW ROHS COMPLIANT PROCESS 
	AND Pb FREE FOR MANUFACTURING

9)	PCB MATERIAL REQUIREMENTS:

	A.	FLAMMABILITY RATING MUST MEET OR EXCEED 
		UL94V-0 REQUIREMENTS.
	B.	Tg 170 C OR EQUIVALENT.
	C.	EQUIVALENT MATERIAL SHALL BE RoHS COMPLIANT, 
		HALOGEN FREE AND APPROVED BY TRENDBIT.

10)	DESIGN GEOMETRY MINIMUM FEATURE SIZES:

	BOARD SIZE				20.100 × 22.007 mm
	BOARD THICKNESS		1.600 mm
	TRACE WIDTH			1.000 mm
	TRACE TO TRACE		0.100 mm
	MIN. HOLE (PTH)			0.500 mm
	MIN. HOLE (NPTH)		N/A mm
	ANNULAR RING			0.250 mm
	COPPER TO HOLE		0.150 mm
	COPPER TO EDGE		0.300 mm
	HOLE TO HOLE			0.250 mm

11)	REFER TO IMPEDANCE TABLE FOR IMPEDANCE CONTROL REQUIREMENTS.

12)	CONFIRM SPACE WIDTHS AND SPACINGS.

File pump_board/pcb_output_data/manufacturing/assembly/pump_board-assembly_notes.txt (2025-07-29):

ASSEMBLY NOTES (UNLESS OTHERWISE SPECIFIED)

1)	DO NOT POPULATE PARTS ARE MARKED WITH A RED CROSS.

2)	DO NOT POPULATE PARTS ARE NOT PRESENT IN THE BOM.

3)	IF CONFLICTING INFORMATION IS FOUND BETWEEN THE ASSEMBLY
	FILE AND BOM, BOM SHOULD BE USED AS THE MAIN SOURCE.

4)	CONFORMAL COATING IS NOT REQUIRED.

5)	DOT IDENTIFIES PIN #1 LOCATION AND DEVICE ORIENTATION
	WHEN VIEWED FROM THE TOP.

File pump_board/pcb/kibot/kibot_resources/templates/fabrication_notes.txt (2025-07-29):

FABRICATION NOTES (UNLESS OTHERWISE SPECIFIED)

1)	FABRICATE PER IPC-6012A CLASS 2.

2)	OUTLINE DEFINED IN SEPARATE GERBER FILE WITH
	"Edge_Cuts.GBR" SUFFIX.

	DIMENSIONS OF CIRCUMSIZED RECTANGLE SHOWN ON THIS
	DRAWING FOR REFERENCE ONLY.

3)	SEE SEPARATE DRILL FILES WITH ".DRL" SUFFIX 
	FOR HOLE LOCATIONS.

	SELECTED HOLE LOCATIONS SHOWN ON THIS DRAWING 
	FOR REFERENCE ONLY.

4)	SURFACE FINISH: ${pcb_finish_cap}

5)	SOLDERMASK ON BOTH SIDES OF THE BOARD SHALL 
	BE LPI, COLOR ${solder_mask_color_text_cap}.

6)	SILK SCREEN LEGEND TO BE APPLIED PER LAYER 
	STACKUP USING ${silk_screen_color_text_cap} NON-CONDUCTIVE EPOXY INK.

7)	ALL VIAS ARE TENTED ON BOTH SIDES UNLESS 
	SOLDERMASK OPENED IN GERBER.

8)	VENDOR SHOULD FOLLOW ROHS COMPLIANT PROCESS 
	AND Pb FREE FOR MANUFACTURING

9)	PCB MATERIAL REQUIREMENTS:

	A.	FLAMMABILITY RATING MUST MEET OR EXCEED 
		UL94V-0 REQUIREMENTS.
	B.	Tg 170 C OR EQUIVALENT.
	C.	EQUIVALENT MATERIAL SHALL BE RoHS COMPLIANT, 
		HALOGEN FREE AND APPROVED BY ${COMPANY_cap}.

10)	DESIGN GEOMETRY MINIMUM FEATURE SIZES:

	BOARD SIZE				${bb_w_mm} × ${bb_h_mm} mm
	BOARD THICKNESS		${thickness_mm} mm
	TRACE WIDTH			${track_mm} mm
	TRACE TO TRACE		${clearance_mm} mm
	MIN. HOLE (PTH)			${drill_pth_real_mm} mm
	MIN. HOLE (NPTH)		${drill_npth_real_mm} mm
	ANNULAR RING			${oar_mm} mm
	COPPER TO HOLE		${c2h_mm} mm
	COPPER TO EDGE		${c2e_mm} mm
	HOLE TO HOLE			${h2h_mm} mm
#?stackup and impedance_controlled

#?stackup and impedance_controlled
11)	REFER TO IMPEDANCE TABLE FOR IMPEDANCE CONTROL REQUIREMENTS.
#?stackup and impedance_controlled

#?stackup and impedance_controlled
12)	CONFIRM SPACE WIDTHS AND SPACINGS.

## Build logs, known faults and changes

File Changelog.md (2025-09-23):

# Changelog

## Fluorometer LED v1.2
#### Added
- Alignment tab was added so board can be easily indexed to correct position on part

#### Changed
- Swap connectors for solder pads
    - Connector placement was not consistent and could result in short to Slug

## Control board v1.2
#### Changed
- Update LED driver input filter values in order to work in both modes:
    - Analog mode, limited to range 25-100% with input frequency of 1 MHz
    - PWM mode, full range but flickering at input frequency of 1 kHz

- Unify motor current sensing resistors for all driver to 150mR
    - Lower threshold cause issues with inrush current
    - Assembly price is lower with only one type of component instead of three types

#### Fixed
- Reduce value of motor filtering capacitors to 10nF (from 1uf)
    - Because sometimes triggered over-current protection of driver 

## Fluorometer LED v1.1
#### Changed
- LED connection was changed from 4S1P to 2S2P
    - This reduces total voltage across LED and enables buck LED driver at 12V

## Sensor board v1.1
#### Fixed
- Incorrect polarity of thermopile amplifier
- Ringing on Emissive spectrophotometer when saturated (new analog filter)
- LED pins are now unified between all modules

## Interface board v1.1
#### Added
- Thermal sensor on I2C bus readable from RPi
- New low-pass filter for current sense

#### Changed
- Use rectifiers for PoE to produce less heat

#### Fixed  
- CAN transceiver mode of operation set as High speed
- CAN transceiver is set to run mode by default

## Control board v1.1
#### Added
- Bulk capacitance to motor drivers
- Additional decoupling capacitor to motor drivers
- Table in schematic with mapping between GPIOs and PWM channels or PIOs
- Add project logo to backside of board

#### Fixed
- Orientation of LED connector and its silkscreen marking is now compatible with Illumination board (Basic RGBW)
    - Swap LED channels (0<->3, 1<->2)
- Modify Fan MOSFET to correct footprint

#### Changed
- Update values of LED signaling resistors for more uniform light intensity
- Change CAN receiver R_s resistor in order to select high-speed mode
    - This could result in higher electromagnetic emission (but almost negligible)
- Select higher precision (5.1k - 0.1%) resistors for temperature sensing
- Exchange on board thermistor for one with more suitable curve (beta 3050 -> 3950)
    - Also package change from 0402 to 0603 (unification of case sizes)
- Update resistor values of fan tachometric filter
    - Cutoff frequency of filter is set to 50Hz
- Change values of motor driver sense resistor
    - Each driver has now different value in order to limit peak current
    - This also enables current control of motor
- Change GPIO connections to have Motor Inputs (IN1, IN2, VREF) controlled by PWM
    - This will enabled motor PWm control with or without current limiting
    - As part of this LED2 was moved from GPIO22 to GPIO24

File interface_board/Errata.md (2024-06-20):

# v1.0

- #1 - Reset pin of CAN transceiver (MCP2515) should be tied to 3.3V otherwise chip will not be registered in RPi
    - Fix: Short pin 19 (RESET) to neighbor pin 20 (VCC) with solder, but it is better to use 10kR resistor

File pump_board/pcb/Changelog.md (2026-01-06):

# Changelog

## [1.0] - 2025-09-25
- Initial release

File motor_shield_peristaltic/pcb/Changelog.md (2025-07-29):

# Changelog

## [1.0] - 2025-07-27
- Initial release

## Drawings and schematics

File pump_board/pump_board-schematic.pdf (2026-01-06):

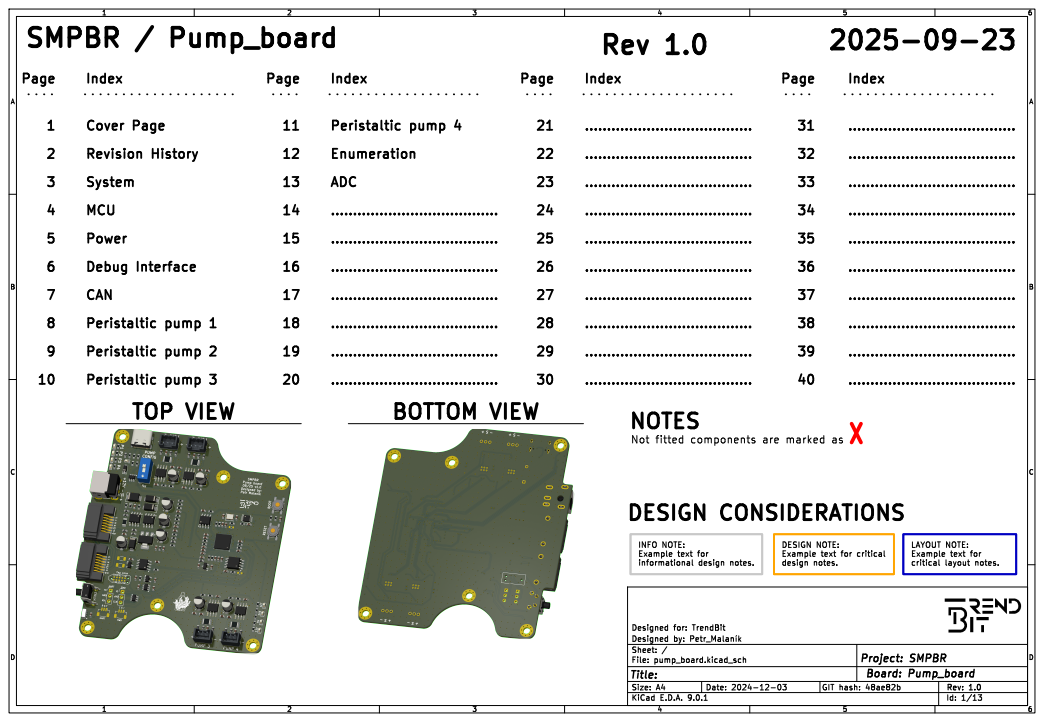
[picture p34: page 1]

INFO NOTE: Example text for

by: þÿPetr_Malaník | Id: 1/13 File: pump_board.kicad_sch Sheet: / Designed

Title: | Board: Pump_board

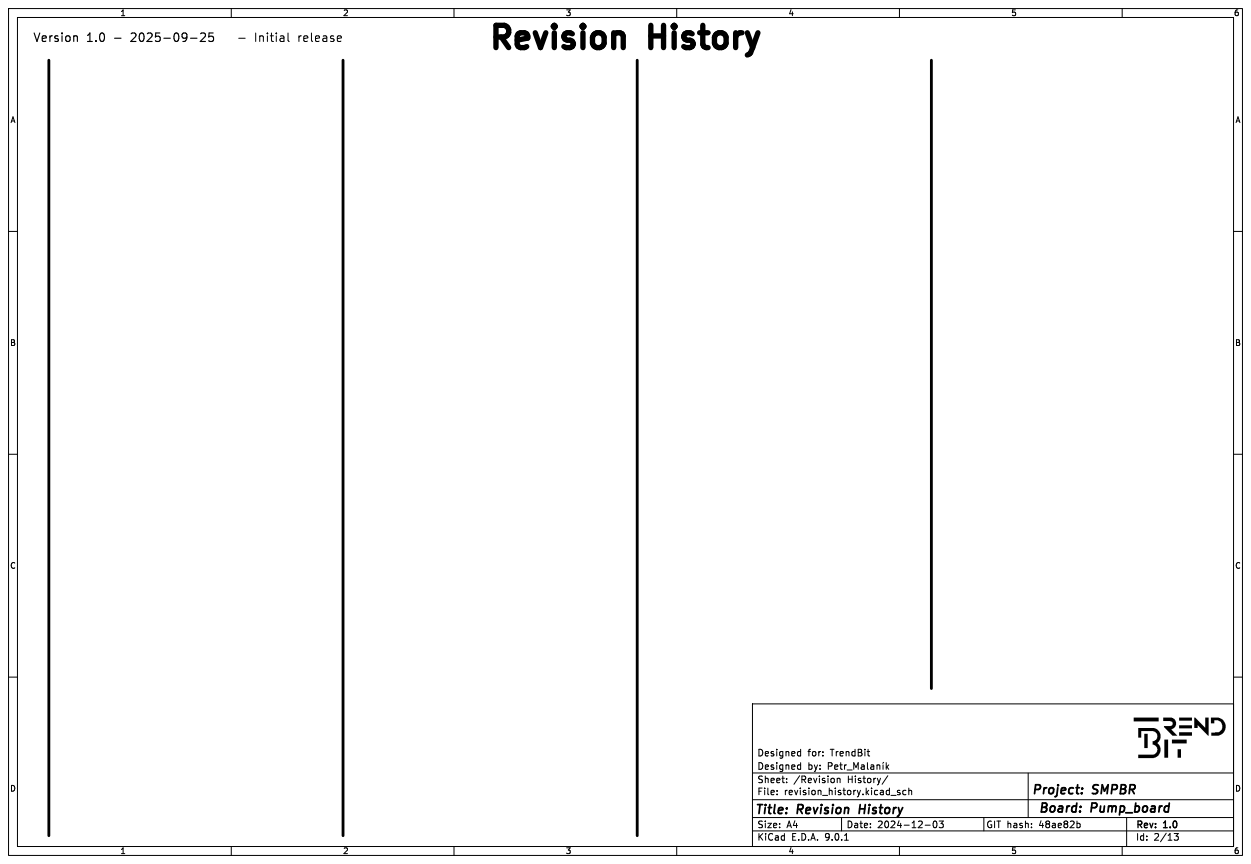
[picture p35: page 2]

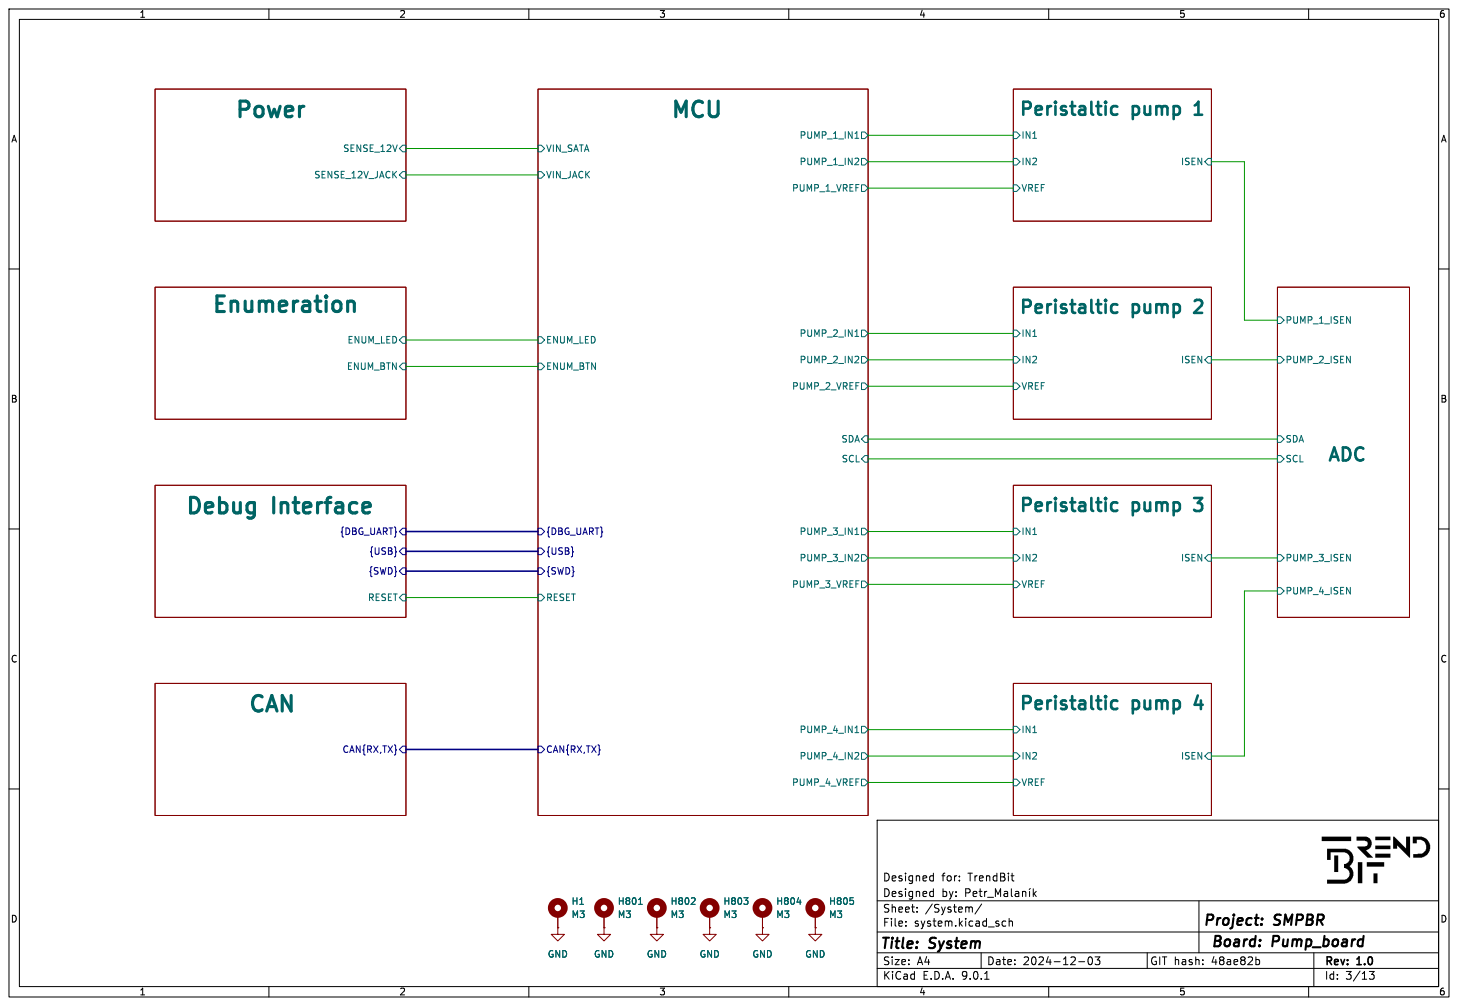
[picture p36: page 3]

Id: 3/13 File: system.kicad_sch Sheet: /System/

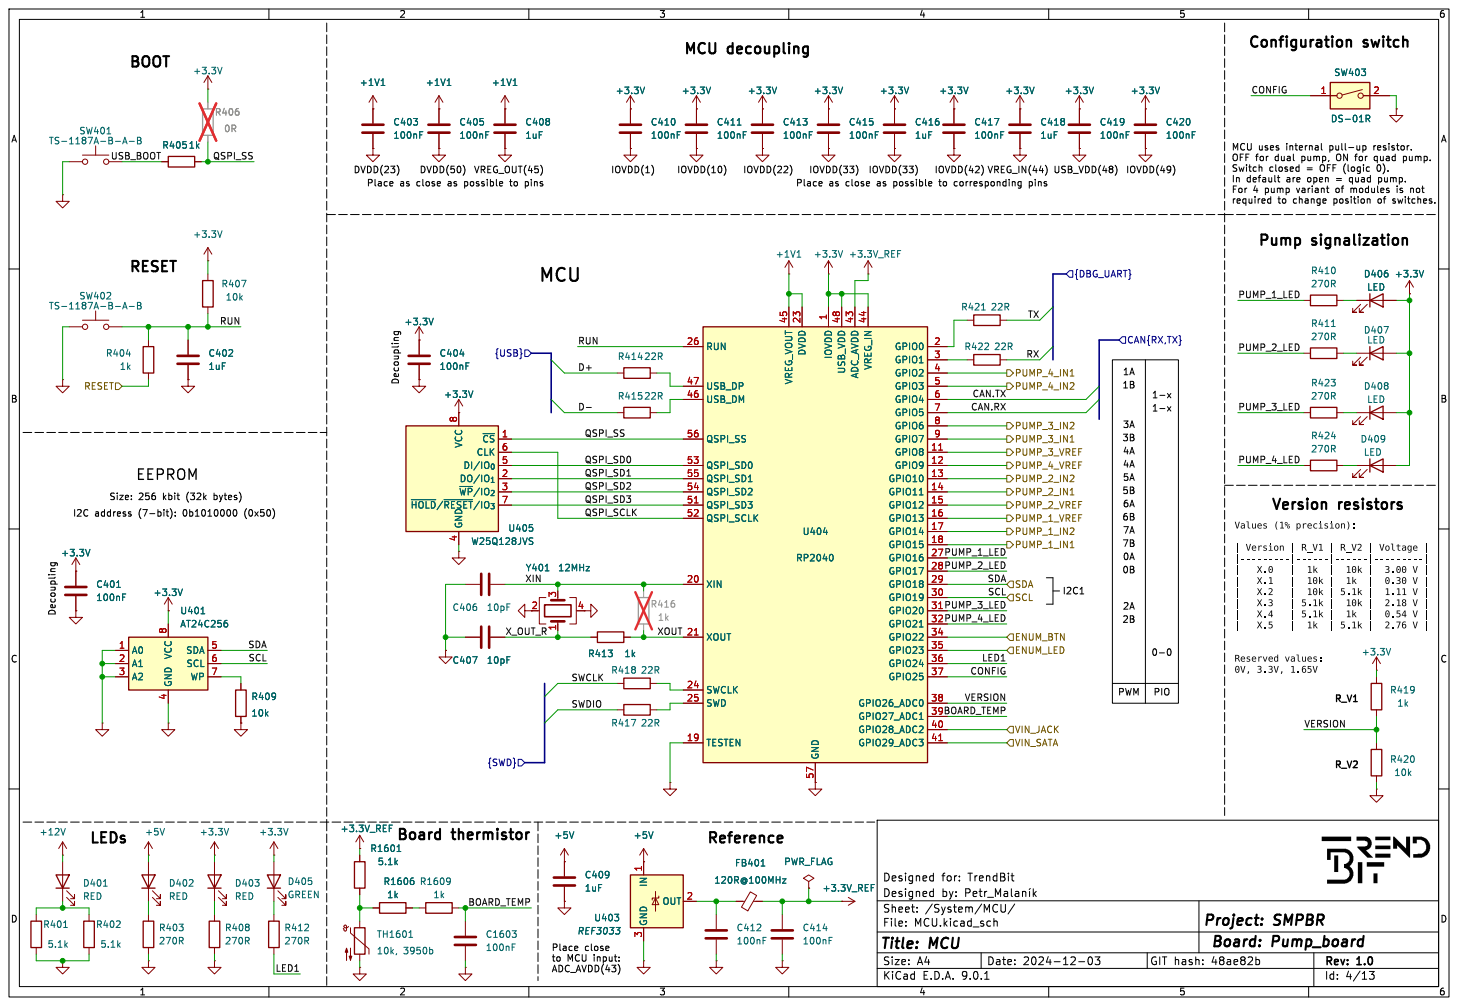
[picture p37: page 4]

Id: 4/13 File: MCU.kicad_sch Sheet: /System/MCU/

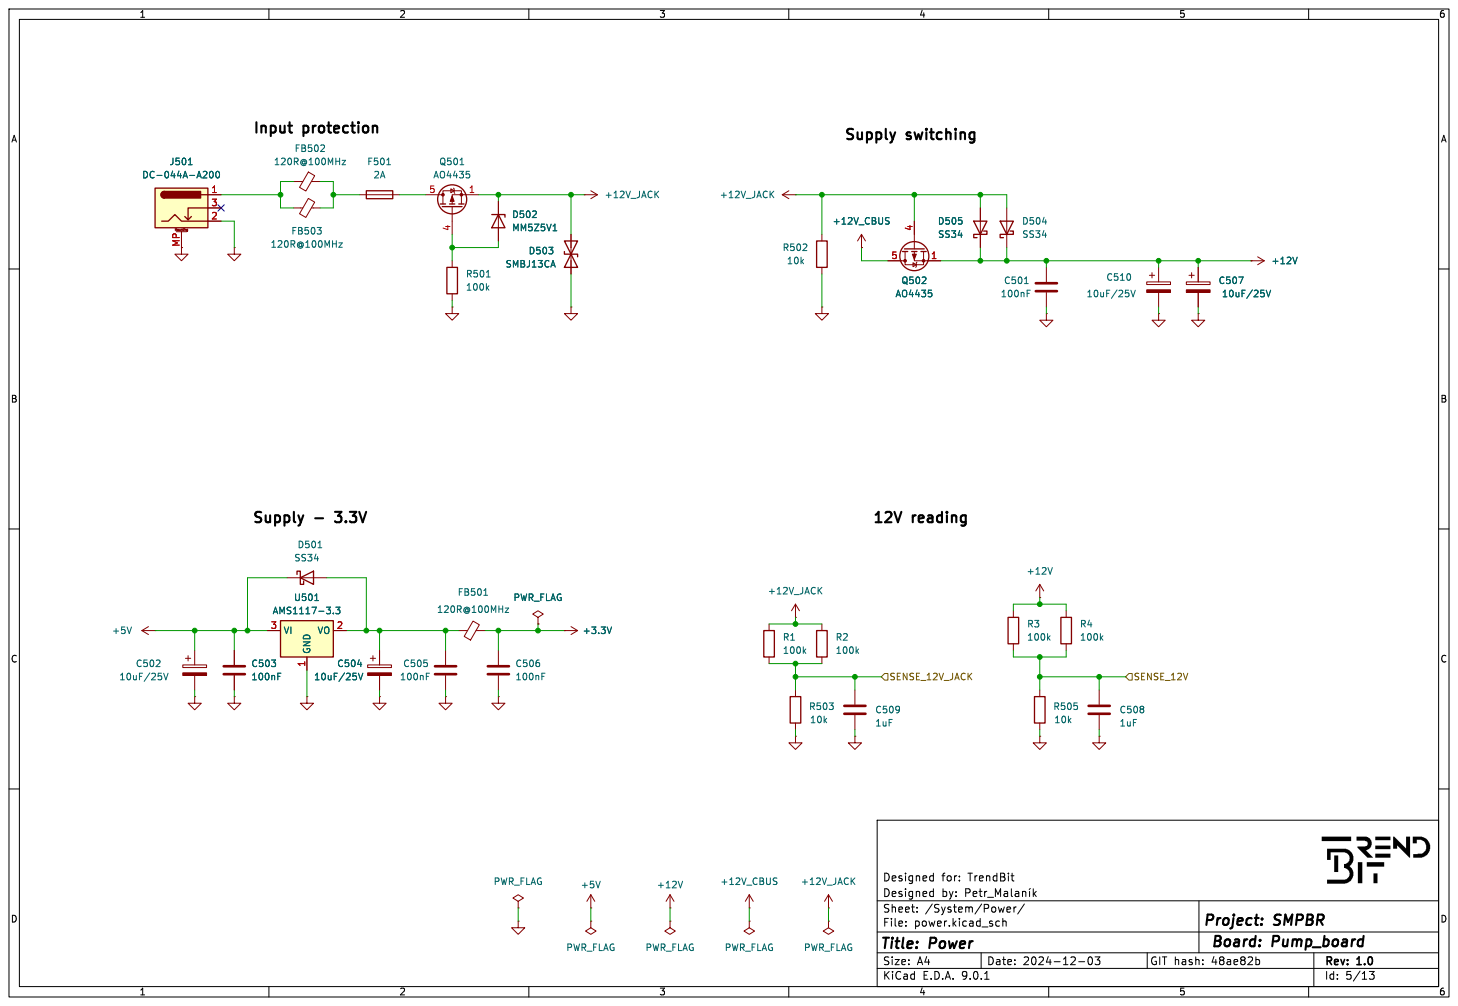
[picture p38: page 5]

Id: 5/13 File: power.kicad_sch Sheet: /System/Power/

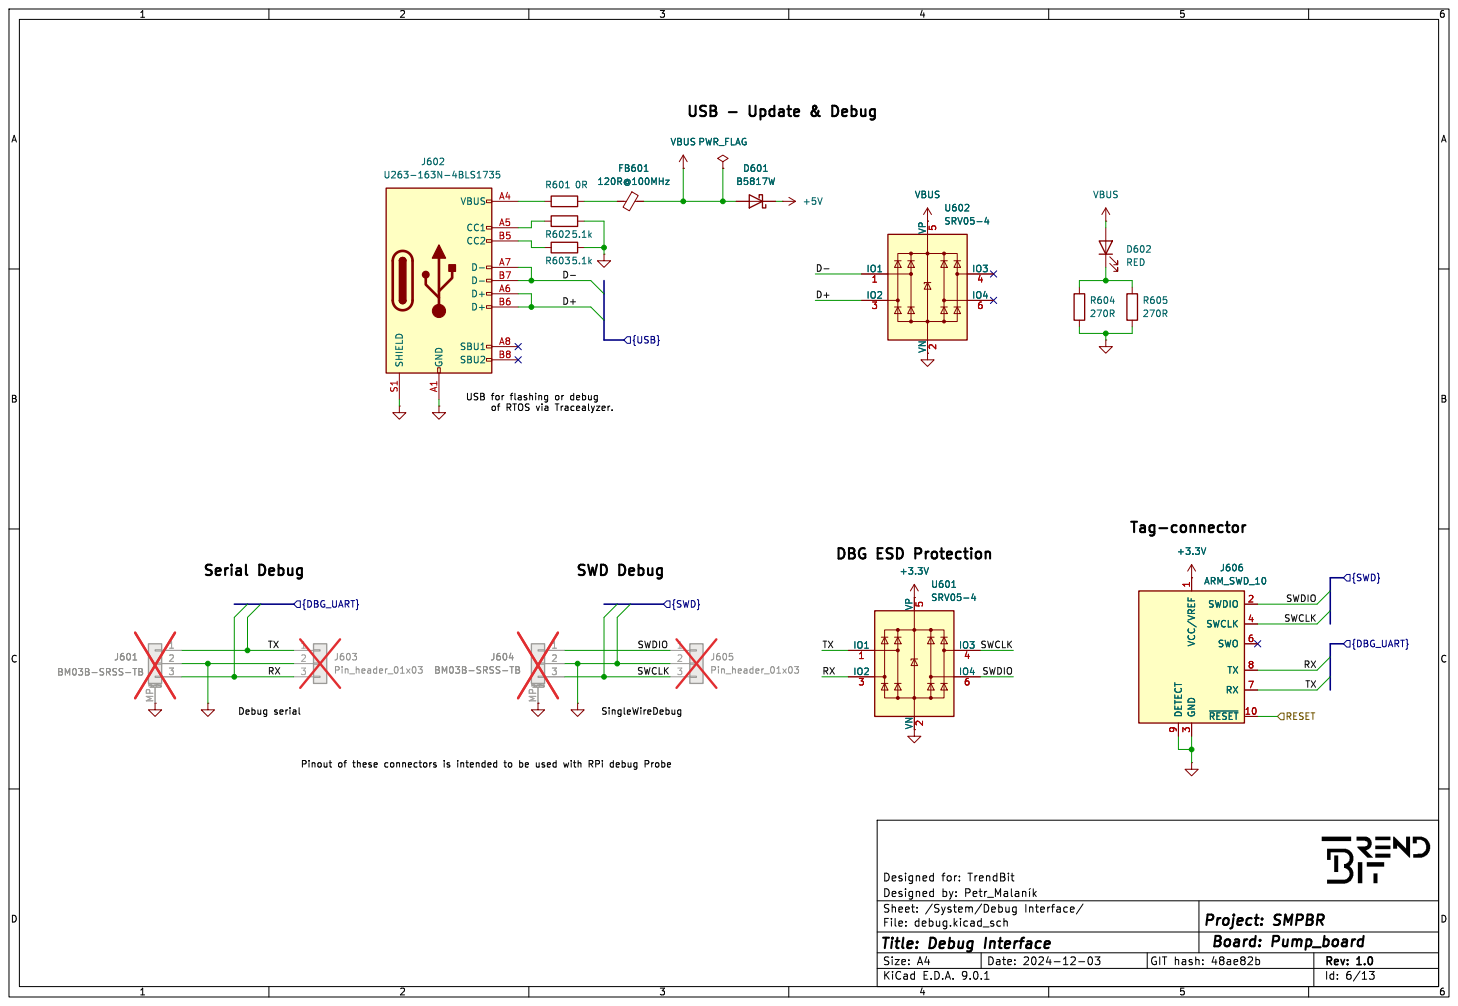
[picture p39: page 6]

3 SWDIO 2 SWCLK 4 SWO 6 TX 8 RX 7 ~{RESET}10

by: þÿPetr_Malaník Interface/ Designed | Id: 6/13 File: debug.kicad_sch Sheet: /System/Debug

Title: Debug Interface | Board: Pump_board

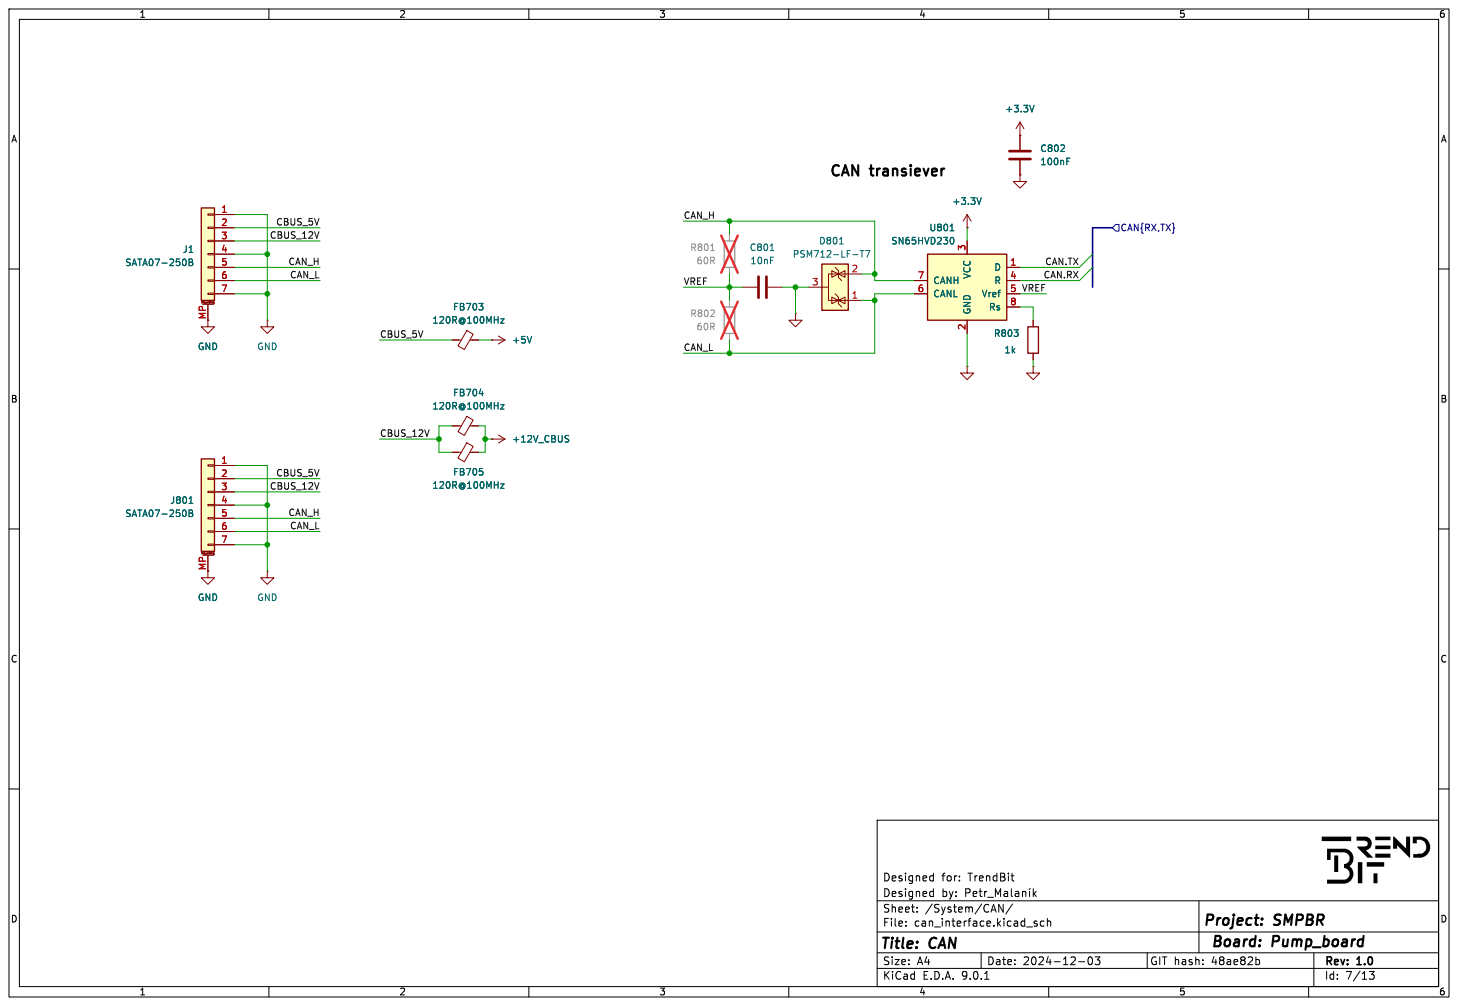
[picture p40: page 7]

Id: 7/13 File: can_interface.kicad_sch Sheet: /System/CAN/

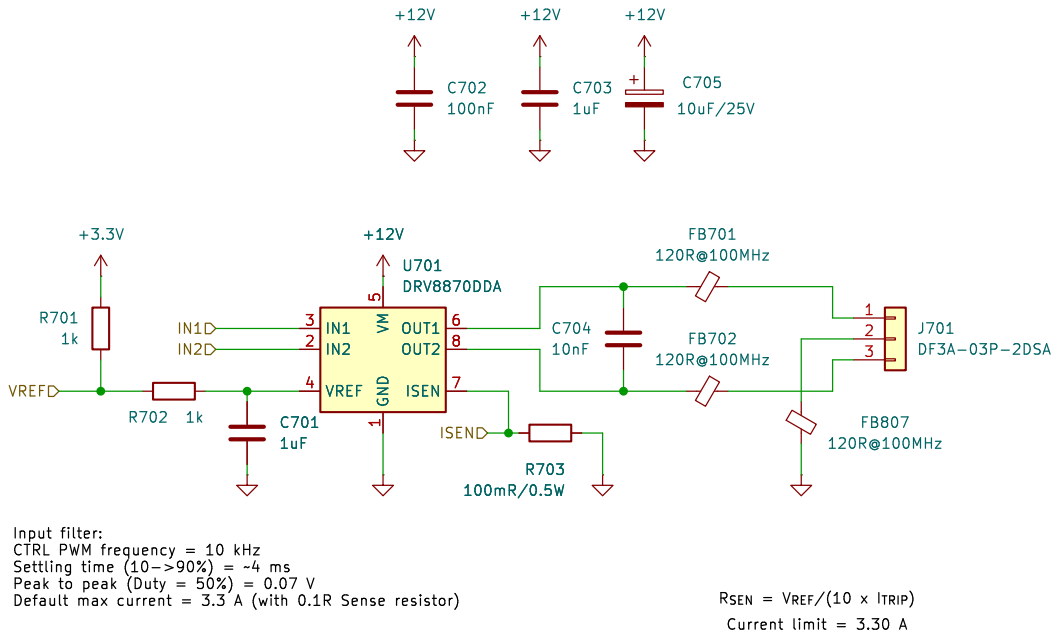
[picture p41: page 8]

R_{SEN} = V_{REF}/(10x I_{TRIP}) Current limit = 3.30 A

by: þÿPetr_Malaník pump 1/ Designed | Id: 8/13 File: motor.kicad_sch Sheet: /System/Peristaltic

Title: Peristaltic pump 1 | Board: Pump_board

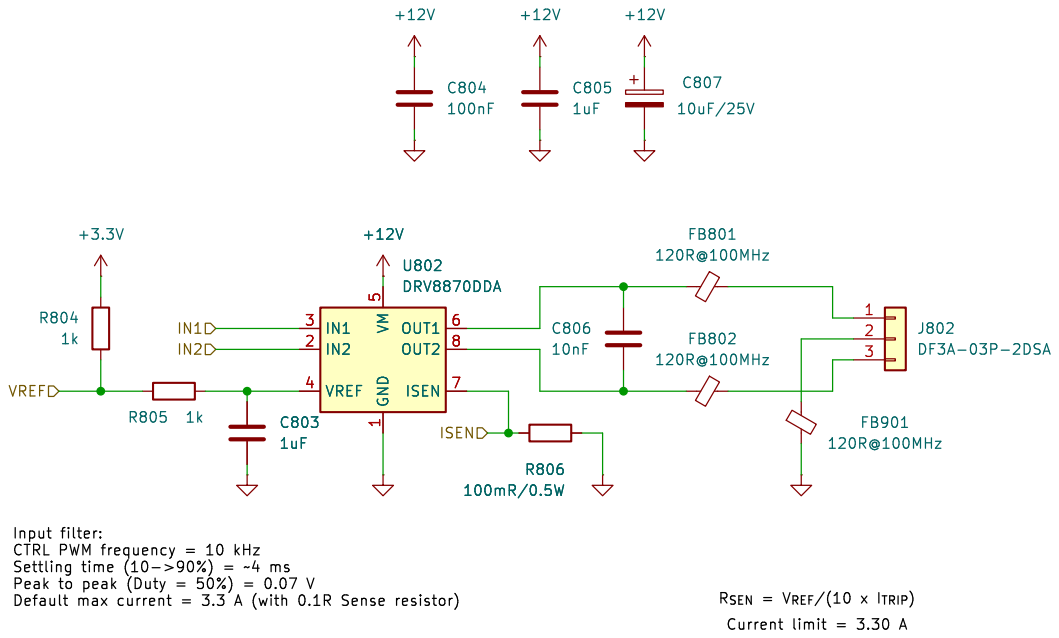
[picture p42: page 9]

R_{SEN} = V_{REF}/(10x I_{TRIP}) Current limit = 3.30 A

by: þÿPetr_Malaník pump 2/ Designed | Id: 9/13 File: motor.kicad_sch Sheet: /System/Peristaltic

Title: Peristaltic pump 2 | Board: Pump_board

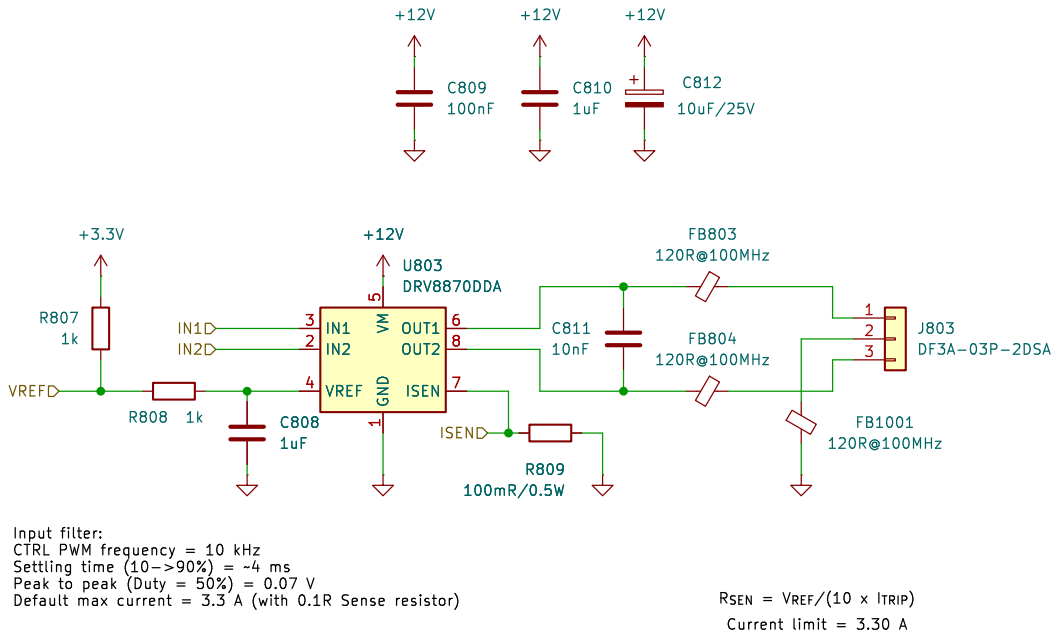
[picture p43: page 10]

R_{SEN} = V_{REF}/(10x I_{TRIP}) Current limit = 3.30 A

by: þÿPetr_Malaník pump 3/ Designed | Id: 10/13 File: motor.kicad_sch Sheet: /System/Peristaltic

Title: Peristaltic pump 3 | Board: Pump_board

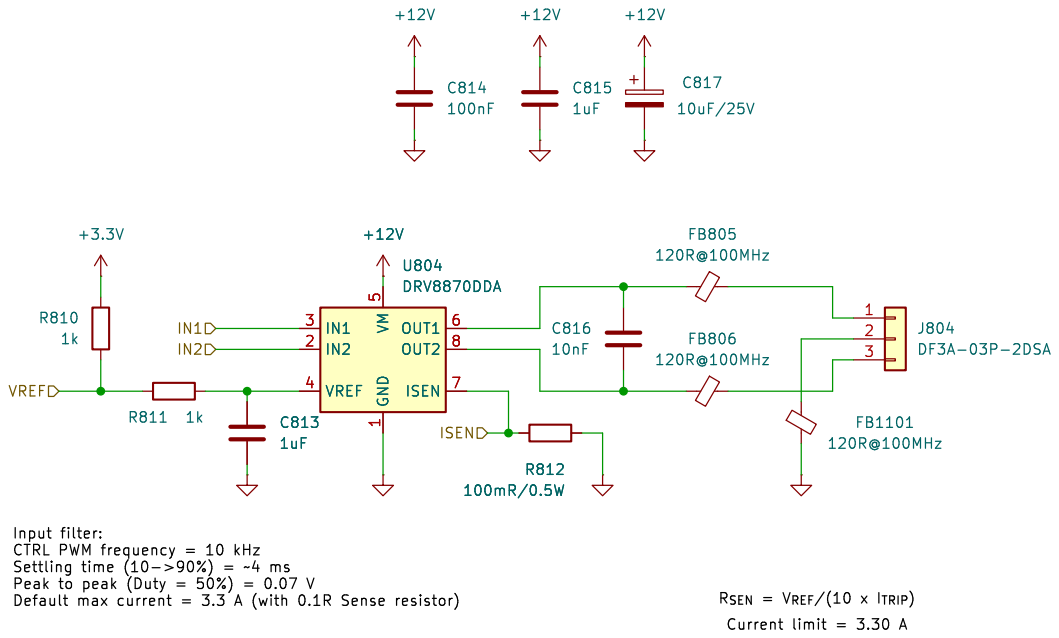
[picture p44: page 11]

R_{SEN} = V_{REF}/(10x I_{TRIP}) Current limit = 3.30 A

by: þÿPetr_Malaník pump 4/ Designed | Id: 11/13 File: motor.kicad_sch Sheet: /System/Peristaltic

Title: Peristaltic pump 4 | Board: Pump_board

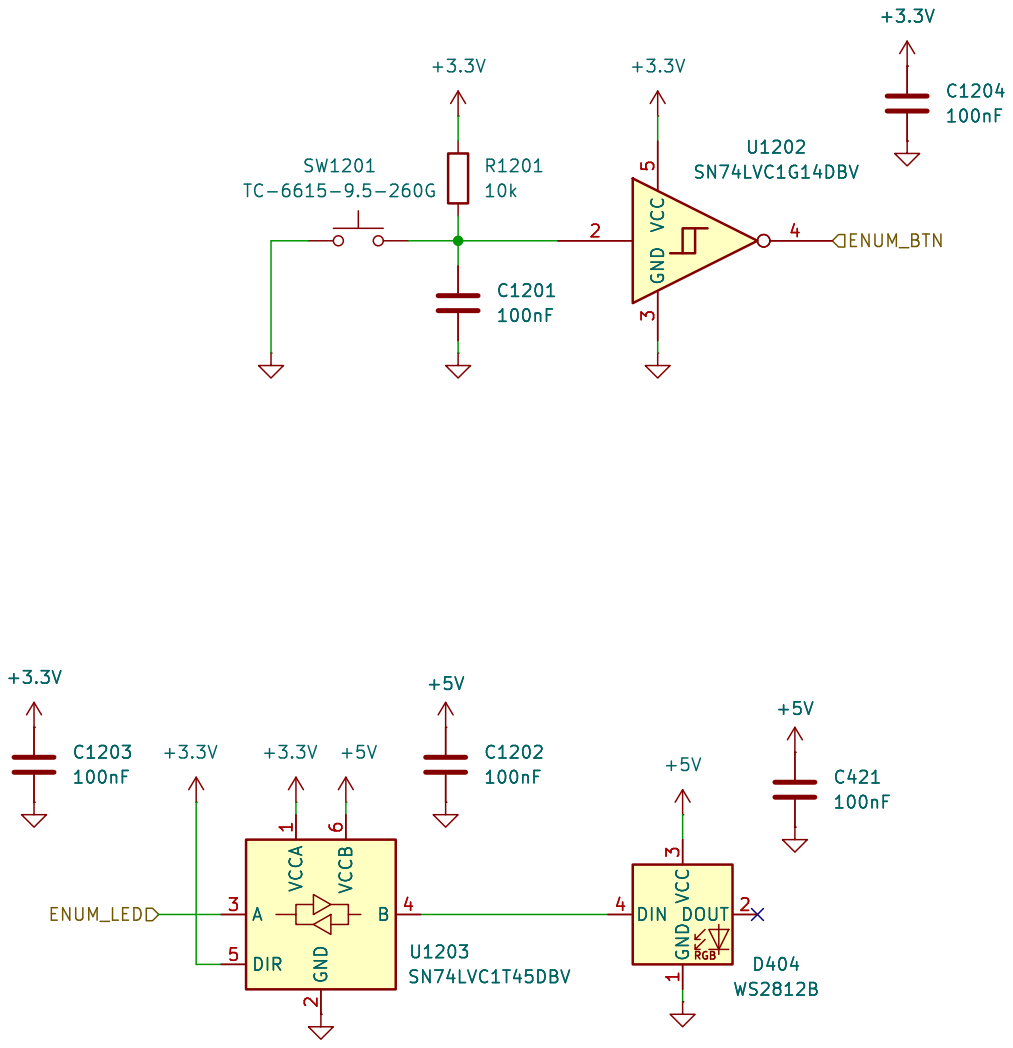
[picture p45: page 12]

Id: 12/13 File: enumeration.kicad_sch Sheet: /System/Enumeration/


3 ALERT/RDY 2 SCL 10 SDA 9 ADDR 1 +3.3V

3 ALERT/RDY 2 SCL 10 SDA 9 ADDR 1 U1301 ADS1115IDGS

Id: 13/13 File: adc.kicad_sch Sheet: /System/ADC/

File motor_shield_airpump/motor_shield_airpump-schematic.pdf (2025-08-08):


INFO NOTE: Example text for

by: þÿPetr_Malaník | Id: 1/3 File: motor_shield_airpump.kicad_sch Sheet: / Designed

Title: | Board: shield_air



Id: 3/3 File: system.kicad_sch Sheet: /System/

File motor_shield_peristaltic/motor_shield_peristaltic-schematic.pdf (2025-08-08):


INFO NOTE: Example text for

by: þÿPetr_Malaník | Id: 1/3 File: motor_shield_peristaltic.kicad_sch Sheet: / Designed

Title: | Board: shield-peristaltic



Id: 3/3 File: system.kicad_sch Sheet: /System/

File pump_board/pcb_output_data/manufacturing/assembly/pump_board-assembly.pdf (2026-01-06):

Board: Pump_board Title:; Project: SMPBR; GIT; hash: e67dce0; Designed; for:; TrendBit; by: Petr_Malaník; Sheet:; File:; pump_board.kicad_pcb; Size: A4; Rev: 1.0; KiCad; E.D.A. 9.0.1+1 + KiBot v1.8.5; Date: 2024-12-04; 6 KIKIT: width: 5mm; KIKIT: width: 5mm

KIKIT: width: 5mm

# Top Assembly (Scale 1:1)


# Bottom Assembly (Scale 1:1)

Board: Pump_board Title:; Project: SMPBR; Designed; for:; TrendBit; by: Petr_Malaník; Sheet:; File:; pump_board.kicad_pcb

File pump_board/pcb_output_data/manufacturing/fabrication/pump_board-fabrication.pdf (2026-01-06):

# Top Fabrication (Scale 1:1)

Project: SMPBR; GIT hash: e67dce0; Size: A4; Rev: 1.0; Date: 2024-12-04; Petr Malaník; Designed by:; Pump board; SMPBR; GND; ENUM; PUMP 3; CLK; SWD; CONFIG; PUMP; ACT; PUMP 4; UART; Tag conn; BOOT; RESET

Designed for: TrendBit
Designed by: Petr_Malaník
Sheet:
File: pump_board.kicad_pcb
Board: Pump_board Title:
KiCad E.D.A. 9.0.1+1 + KiBot v1.8.5

# Bottom Fabrication (Scale 1:1)

Board: Pump_board Title:; Project: SMPBR; Designed; for:; TrendBit; by: Petr_Malaník; Sheet:; File:; pump_board.kicad_pcb

# Drill Drawing L1 - L4 (Scale 1:1)

Board: Pump_board Title:; Project: SMPBR; Designed; for:; TrendBit; by: Petr_Malaník; Sheet:; File:; pump_board.kicad_pcb

# Drill Drawing L1 - L4 (Scale 1:1)

Board: Pump_board Title:; Project: SMPBR; Designed; for:; TrendBit; by: Petr_Malaník; Sheet:; File:; pump_board.kicad_pcb

# Top Test Points (Scale 1:1)

Project: SMPBR; Petr Malaník; Designed by:; Pump board; SMPBR; GND; ENUM; PUMP 3; CLK; SWD; CONFIG; PUMP; ACT; PUMP 4; UART; Tag conn; BOOT; RESET

Designed for: TrendBit
Designed by: Petr_Malaník
Sheet:
File: pump_board.kicad_pcb
Board: Pump_board Title:

# Bottom Test Points (Scale 1:1)

Board: Pump_board Title:; Project: SMPBR; Designed; for:; TrendBit; by: Petr_Malaník; Sheet:; File:; pump_board.kicad_pcb

# L1 (Sig) (Scale 1:1)

Board: Pump_board Title:; Project: SMPBR; Designed; for:; TrendBit; by: Petr_Malaník; Sheet:; File:; pump_board.kicad_pcb

# L2 (GND) (Scale 1:1)

Board: Pump_board Title:; Project: SMPBR; Designed; for:; TrendBit; by: Petr_Malaník; Sheet:; File:; pump_board.kicad_pcb

# L3 (PWR) (Scale 1:1)

Board: Pump_board Title:; Project: SMPBR; Designed; for:; TrendBit; by: Petr_Malaník; Sheet:; File:; pump_board.kicad_pcb

# L4 (Sig,) (Scale 1:1)

Board: Pump_board Title:; Project: SMPBR; Designed; for:; TrendBit; by: Petr_Malaník; Sheet:; File:; pump_board.kicad_pcb

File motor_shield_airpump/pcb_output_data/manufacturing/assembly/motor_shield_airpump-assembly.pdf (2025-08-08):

Board: shield_air Title:; Project: SMPBR; GIT; hash: 5b9075c; Designed; for:; TrendBit; by: Petr_Malaník; Sheet: File: motor_shield_airpump.kicad_pcb; Size: A4; Rev: 1.0; KiCad; E.D.A. 9.0.1+1 + KiBot v1.8.5; Date: 2024-12-04

# Top Assembly (Scale 1:1)


# Bottom Assembly (Scale 1:1)

Board: shield_air Title:; Project: SMPBR; Designed; for:; TrendBit; by: Petr_Malaník; Sheet: File: motor_shield_airpump.kicad_pcb; Petr Malaník; Designed by:

Motor filter shield
Air pump

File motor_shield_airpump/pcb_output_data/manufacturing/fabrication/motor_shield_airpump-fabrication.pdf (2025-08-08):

# Top Fabrication (Scale 1:1)

Project: SMPBR; GIT hash: 5b9075c; Size: A4; Rev: 1.0; KiCad; E.D.A. 9.0.1+1 + KiBot v1.8.5; Date: 2024-12-04

Designed for: TrendBit
Designed by: Petr_Malaník
Sheet:
File: motor_shield_airpump.kicad_pcb
Board: shield_air Title:

# Bottom Fabrication (Scale 1:1)

Board: shield_air Title:; Project: SMPBR; Designed; for:; TrendBit; by: Petr_Malaník; Sheet: File: motor_shield_airpump.kicad_pcb; Air pump; Petr Malaník; Designed by:; Motor; filter shield

# Drill Drawing L1 - L2 (Scale 1:1)

Board: shield_air Title:; Project: SMPBR; Designed; for:; TrendBit; by: Petr_Malaník; Sheet: File: motor_shield_airpump.kicad_pcb

# Top Test Points (Scale 1:1)

Board: shield_air Title:; Project: SMPBR; Designed; for:; TrendBit; by: Petr_Malaník; Sheet: File: motor_shield_airpump.kicad_pcb

# Bottom Test Points (Scale 1:1)

Board: shield_air Title:; Project: SMPBR; Designed; for:; TrendBit; by: Petr_Malaník; Sheet: File: motor_shield_airpump.kicad_pcb; Petr Malaník; Designed by:

Motor filter shield
Air pump

# F.Cu (Scale 1:1)

Board: shield_air Title:; Project: SMPBR; Designed; for:; TrendBit; by: Petr_Malaník; Sheet: File: motor_shield_airpump.kicad_pcb

# B.Cu (Scale 1:1)

Board: shield_air Title:; Project: SMPBR; Designed; for:; TrendBit; by: Petr_Malaník; Sheet: File: motor_shield_airpump.kicad_pcb

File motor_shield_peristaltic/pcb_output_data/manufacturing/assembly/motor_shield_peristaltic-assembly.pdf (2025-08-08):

Project: SMPBR; GIT; hash: 5b9075c; Designed; for:; TrendBit; by: Petr_Malaník; Size: A4; Rev: 1.0; KiCad; E.D.A. 9.0.1+1 + KiBot v1.8.5; Date: 2024-12-04

Sheet:
File: motor_shield_peristaltic.kicad_pcb
Board: shield-peristaltic Title:

# Top Assembly (Scale 1:1)

Project: SMPBR; Designed; for:; TrendBit; by: Petr_Malaník

Sheet:
File: motor_shield_peristaltic.kicad_pcb
Board: shield-peristaltic Title:

# Bottom Assembly (Scale 1:1)

Project: SMPBR; Designed; for:; TrendBit; by: Petr_Malaník; Peristaltic pump; Petr Malaník; Designed by:

Motor filter shield

Sheet:
File: motor_shield_peristaltic.kicad_pcb
Board: shield-peristaltic Title:

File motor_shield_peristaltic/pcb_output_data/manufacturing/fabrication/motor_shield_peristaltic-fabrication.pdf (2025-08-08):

# Top Fabrication (Scale 1:1)

Project: SMPBR; GIT hash: 5b9075c; Designed; for:; TrendBit; by: Petr_Malaník; Size: A4; Rev: 1.0; KiCad; E.D.A. 9.0.1+1 + KiBot v1.8.5; Date: 2024-12-04

Sheet:
File: motor_shield_peristaltic.kicad_pcb
Board: shield-peristaltic Title:

# Bottom Fabrication (Scale 1:1)

Project: SMPBR; Designed; for:; TrendBit; by: Petr_Malaník; Peristaltic pump; Petr Malaník; Designed by:

Motor filter shield

Sheet:
File: motor_shield_peristaltic.kicad_pcb
Board: shield-peristaltic Title:

# Drill Drawing L1 - L2 (Scale 1:1)

Project: SMPBR; Designed; for:; TrendBit; by: Petr_Malaník

Sheet:
File: motor_shield_peristaltic.kicad_pcb
Board: shield-peristaltic Title:

# Top Test Points (Scale 1:1)

Project: SMPBR; Designed; for:; TrendBit; by: Petr_Malaník

Sheet:
File: motor_shield_peristaltic.kicad_pcb
Board: shield-peristaltic Title:

# Bottom Test Points (Scale 1:1)

Project: SMPBR; Designed; for:; TrendBit; by: Petr_Malaník; Peristaltic pump; Petr Malaník; Designed by:

Motor filter shield

Sheet:
File: motor_shield_peristaltic.kicad_pcb
Board: shield-peristaltic Title:

# F.Cu (Scale 1:1)

Project: SMPBR; Designed; for:; TrendBit; by: Petr_Malaník

Sheet:
File: motor_shield_peristaltic.kicad_pcb
Board: shield-peristaltic Title:

# B.Cu (Scale 1:1)

Project: SMPBR; Designed; for:; TrendBit; by: Petr_Malaník

Sheet:
File: motor_shield_peristaltic.kicad_pcb
Board: shield-peristaltic Title:

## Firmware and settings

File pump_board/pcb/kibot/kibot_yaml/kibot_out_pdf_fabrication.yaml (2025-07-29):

# KiBot output for generating Fabrication Document in PDF format
# https://kibot.readthedocs.io/en/latest/configuration/outputs/pcb_print.html

kibot:
  version: 1

outputs:
- name: @NAME@
  comment: '@COMMENT@'
  type: pcb_print
  category: '@DIR@'
  dir: '@DIR@'
  options:
    colored_pads: false
    colored_vias: false
    color_theme: '@COLOR_THEME@'
    output: '%f-fabrication%I%v.%x'
    format: 'PDF'
    title: '@DOC_TITLE@ Document'
    realistic_solder_mask: false
    dpi: 1200
    dnf_filter: _kibom_dnf_Config
    frame_plot_mechanism: 'internal'
    sheet_reference_layout: '@SHEET_WKS@'
    drill:
      unify_pth_and_npth: '@PTH_NPTH@'
      group_slots_and_round_holes: @GROUP_ROUND_SLOTS@
    include_table:
      outputs:
        - name: '@NAME_TP_TOP@'
          text_alignment: 'left'
          invert_columns_order: false
          border_width: 0.4
          header_rule_width: 0.2
          horizontal_rule_width: 0
          vertical_rule_width: 0.2
          top_rule_width: 0.2
          bottom_rule_width: 0.2
          column_spacing: 2
          force_font_width: 1.27 # mm
        - name: '@NAME_TP_BOTTOM@'
          text_alignment: 'right'
          invert_columns_order: true
          border_width: 0.4
          header_rule_width: 0.2
          horizontal_rule_width: 0
          vertical_rule_width: 0.2
          top_rule_width: 0.2
          bottom_rule_width: 0.2
          column_spacing: 2
          force_font_width: 1.27 # mm
        - name: '@NAME_IMPEDANCE_TABLE@'
          text_alignment: 'left'
          invert_columns_order: false
          border_width: 0.4
          header_rule_width: 0.2
          horizontal_rule_width: 0
          vertical_rule_width: 0.2
          top_rule_width: 0.2
          bottom_rule_width: 0.2
          row_spacing: 3
          column_spacing: 2
          row_spacing: 3
        - name: '@NAME_DRILL_TABLE@'
          text_alignment: 'left'
          invert_columns_order: false
          border_width: 0.4
          header_rule_width: 0.2
          horizontal_rule_width: 0
          vertical_rule_width: 0.2
          top_rule_width: 0.2
          bottom_rule_width: 0.2
          row_spacing: 3
          column_spacing: 2
          force_font_width: 1 # mm

    pages:
      - scaling: @SCALING@
        title: '@DOC_TITLE@'
        sheet: 'Top Fabrication (Scale @SCALING@:1)'
        layer_var: 'Top Fabrication (Scale @SCALING@:1)'
        sheet_reference_color: '#000000'
        colored_holes: true
        holes_color: "#FFFFFF"
        layers:
          - layer: Edge.Cuts
            color: '#000000'
          - layer: F.Cu
            color: '#F2F2F2'
          - layer: F.Mask
            color: '#E2E2E2'
          - layer: F.Paste
            color: '#E2E2E2'
          - layer: F.Silkscreen
            color: '#DBDBDB'
          - layer: F.Fab
            plot_footprint_refs: false
            plot_footprint_values: false
            color: '#818181'
          - layer: F.Dimensions
            color: '#000000'

      - scaling: @SCALING@
        mirror: true
        mirror_pcb_text: false
        title: '@DOC_TITLE@'
        sheet: 'Bottom Fabrication (Scale @SCALING@:1)'
        layer_var: 'Bottom Fabrication (Scale @SCALING@:1)'
        sheet_reference_color: '#000000'
        colored_holes: true
        holes_color: "#FFFFFF"
        layers:
          - layer: Edge.Cuts
            color: '#000000'
          - layer: B.Cu
            color: '#F2F2F2'
          - layer: B.Mask
            color: '#E2E2E2'
          - layer: B.Paste
            color: '#E2E2E2'
          - layer: B.Silkscreen
            color: '#DBDBDB'
          - layer: B.Fab
            plot_footprint_refs: false
            plot_footprint_values: false
            color: '#818181'
          - layer: B.Dimensions
            color: '#000000'

      - scaling: @SCALING@
        title: '@DOC_TITLE@'
        sheet: 'Drill Drawing (%lp)'
        layer_var: 'Drill Drawing %lp (Scale @SCALING@:1)'
        sheet_reference_color: '#000000'
        colored_holes: true
        holes_color: "#FFFFFF"
        repeat_for_layer: '@LAYER_DRILL_MAP@'
        repeat_layers: 'drill_pairs'
        layers:
          - layer: '@LAYER_DRILL_MAP@'
            color: '#000000'
          - layer: 'Edge.Cuts'
            color: '#000000'
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

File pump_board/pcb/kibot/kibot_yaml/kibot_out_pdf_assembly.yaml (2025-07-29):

# KiBot output for generating Assembly Document in PDF format
# https://kibot.readthedocs.io/en/latest/configuration/outputs/pcb_print.html

kibot:
  version: 1

outputs:
- name: @NAME@
  comment: '@COMMENT@'
  type: pcb_print
  category: '@DIR@'
  dir: '@DIR@'
  options:
    colored_vias: false
    colored_pads: false
    color_theme: '@COLOR_THEME@'
    output: '%f-assembly%I%v.%x'
    format: 'PDF'
    title: '@DOC_TITLE@ Document'
    realistic_solder_mask: false
    dpi: 1200
    dnf_filter: _kibom_dnf_Config
    # dnf_filter: '_null'
    sheet_reference_layout: '@SHEET_WKS@'
    include_table:
      outputs:
        - name: '@NAME_COMP_COUNT@'
          text_alignment: 'left'
          invert_columns_order: false
          border_width: 0.4
          header_rule_width: 0.2
          horizontal_rule_width: 0
          vertical_rule_width: 0
          top_rule_width: 0
          bottom_rule_width: 0
          row_spacing: 3
          column_spacing: 2
    pages:
      - scaling: @SCALING@
        layer_var: ''
        title: '@DOC_TITLE@'
        sheet: Top/Bottom View
        sheet_reference_color: '#000000'
        layers:
          - layer: '@LAYER_TITLE_PAGE@'
            color: '#000000'

      - scaling: @SCALING@
        layer_var: "Top Assembly (Scale @SCALING@:1)"
        title: '@DOC_TITLE@'
        sheet: Top Assembly (Scale @SCALING@:1)
        sheet_reference_color: '#000000'
        colored_holes: true
        holes_color: "#FFFFFF"
        layers:
          - layer: Edge.Cuts
            color: '#000000'
          - layer: F.Cu
            color: '#EEDAB5'
          - layer: F.Mask
            color: '#B9B9B9'
          - layer: F.Paste
            color: '#E1A98E'
          - layer: F.Silkscreen
            color: '#DB9DE1'
          - layer: F.Fab
            exclude_filter: '@FAB_EXCLUDE_FILTER@'
            color: '#744679'
          - layer: '@LAYER_ASSEMBLY_TEXT_TOP@'
            color: '#000000'
          - layer: '@LAYER_DNP_CROSS_TOP@'
            color: '#D63034'

      - scaling: @SCALING@
        layer_var: "Bottom Assembly (Scale @SCALING@:1)"
        mirror: true
        mirror_pcb_text: false
        title: '@DOC_TITLE@'
        sheet: Bottom Assembly (Scale @SCALING@:1)
        sheet_reference_color: '#000000'
        colored_holes: true
        holes_color: "#FFFFFF"
        layers:
          - layer: Edge.Cuts
            color: '#000000'
          - layer: B.Cu
            color: '#D5DBF4'
          - layer: B.Mask
            color: '#B9B9B9'
          - layer: B.Paste
            color: '#BCB9DD'
          - layer: B.Silkscreen
            color: '#DB9DE1'
          - layer: B.Fab
            exclude_filter: '@FAB_EXCLUDE_FILTER@'
            color: '#400080'
          - layer: '@LAYER_ASSEMBLY_TEXT_BOTTOM@'
            color: '#000000'
          - layer: '@LAYER_DNP_CROSS_BOTTOM@'
            color: '#D63034'

...
definitions:
  NAME: pdf_assembly
  COMMENT: Assembly document in PDF format
  DIR: Manufacturing/Assembly
  DOC_TITLE: Assembly
  COLOR_THEME: _builtin_classic
  SHEET_WKS: ${KIPRJMOD}/Templates/KDT_Template_PCB_GIT_A4.kicad_wks
  SCALING: 1.0
  FAB_EXCLUDE_FILTER: exclude_testpoints
  LAYER_TITLE_PAGE: TitlePage
  LAYER_ASSEMBLY_TEXT_TOP: F.AssemblyText
  LAYER_ASSEMBLY_TEXT_BOTTOM: B.AssemblyText
  LAYER_DNP_CROSS_TOP: F.DNP
  LAYER_DNP_CROSS_BOTTOM: B.DNP
  NAME_COMP_COUNT: csv_comp_count

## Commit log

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2024-06-20 interface_board: add Errata (CAN transceiver reset resistor)
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2024-06-22 sensor_board: finalize routing of board #2 and #3
    [Thermometer_#2.kicad_sch, Thermopile.kicad_sch, sensor_board.kicad_pcb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]
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2024-06-23 sensor_board: move resources into separate folder, add mechanical drawings
    [I2C_address_space.ods, SM_1_Edges.dxf, SM_1_Mechanical.dxf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]
2024-06-23 sensor_board: fix shifted top thermopile
    [sensor_board.kicad_pcb]
2024-06-23 sensor_board: fix tab position for panelization
    [sensor_board.kicad_pcb]
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2024-08-20 sensor_board: update LCSC MPN assigned to components for manufacturing of board
    [ES_LED_Driver.kicad_sch, ES_LED_Receiver.kicad_sch, MCU.kicad_sch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]
2024-08-28 control_board: update led resistors and can speed selection to high-speed
    [MCU.kicad_sch, can_interface.kicad_sch, control_board.kicad_pcb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]
2024-08-28 control_board: fix LED connector orientation
    [MCU.kicad_sch, control_board.kicad_pcb, led_drivers.kicad_sch]
2024-08-28 control_board: change onboard thermistor for one with more suitable beta
    [control_board.kicad_pcb, thermistors.kicad_sch]
2024-08-28 control_board: update values of fan tacho filter based on experiments
    [control_board.kicad_pcb, fan.kicad_sch]
2024-08-28 control_board: add bulk capacitor to motors, update motor sense resistors
    [control_board.kicad_pcb, fan.kicad_sch, motor.kicad_sch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]
2024-08-28 control_board: fix fan mosfet pinout
    [MCU.kicad_sch, control_board.kicad_pcb, fan.kicad_sch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]
2024-08-28 control_board: reconnect GPIOs to have motor INs controlled by PWM
    [MCU.kicad_sch, control_board.kicad_pcb]
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2024-10-09 control_board: unify motor sense resistor and reduce filtering capacitors
    [motor.kicad_sch, motors.kicad_sch]
2024-10-09 control_board: reduce filtering of led driver control (two modes)
    [led_driver.kicad_sch]
2024-10-09 control_board: bump up the version, update the changelog
    [control_board.kicad_pcb]
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2024-10-24 control_board: update version resistors, fix version in silkscreen
    [MCU.kicad_sch, control_board.kicad_pcb]
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2024-11-25 expansion_sata: add silkscreen with header and usage description
    [expansion_sata.kicad_pcb, expansion_sata.kicad_sch]
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2024-11-25 fluorometer_led: new aluminium backed pcb, used as adapter for high power led
    [fluorometer_led.kicad_pcb, fluorometer_led.kicad_sch]
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2024-11-25 sensor_board: exchange LEd boost convert to buck for different module (2S2P)
    [ES_LED_Driver.kicad_sch, MCU.kicad_sch, SM_1.kicad_sch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]
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2024-12-09 interface_board: lower cutoff frequency of low-pass filter for sense
    [PoE.kicad_sch, Power_input.kicad_sch, Power_supply.kicad_sch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]
2024-12-09 interface_board: fix CAN transceiver reset mode of operation
    [CAN.kicad_sch, interface_board.kicad_pcb]
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2024-12-09 interface_board: replace PoE rectifier, add ORing diode in parallel
    [PoE.kicad_sch, Power_input.kicad_sch, Power_supply.kicad_sch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]
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2024-12-10 interface_board: update LCSC part numbers based on stock
    [ADC.kicad_sch, CAN.kicad_sch, Fan.kicad_sch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]
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2024-12-12 sensor_board: update position of KiKit tabs to match opposite boards
    [sensor_board.kicad_pcb]
2024-12-16 sensor_board: add project logo, various minor fixes in silkscreen
    [sensor_board.kicad_pcb]
2024-12-16 sensor_board: change CAN speed selection to high-speed mode
    [Power_supply.kicad_sch, sensor_board.kicad_pcb]
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2024-12-16 sensor_board: update ES receiver on board #2 (new filters, reference load)
    [ES_LED_Receiver.kicad_sch, Power_supply.kicad_sch, sensor_board.kicad_pcb]
2024-12-16 sensor_board: swap thermopile opAmp inputs, route TS receiver
    [TS_Receiver.kicad_sch, Thermopile.kicad_sch, sensor_board.kicad_pcb]
2024-12-16 sensor_board: remove LED filter capacitor from BOM (DNP)
    [ES_LED_Driver.kicad_sch, sensor_board.kicad_pcb]
2024-12-16 sensor_board: fix KiKit markings and resulting DRC warnings
    [sensor_board.kicad_pcb]
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2024-12-16 sensor_board: update display connector pinout to match OLED pinheader
    [Display.kicad_sch, sensor_board.kicad_pcb]
2024-12-16 sensor_board: optimize routing on board #1 (stitching vias)
    [sensor_board.kicad_pcb]
2024-12-16 sensor_board: add description and marking to thermometers on PCB
    [Thermometer_#2.kicad_sch, Thermometer_#3.kicad_sch, sensor_board.kicad_pcb]
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2024-12-17 interface_board: fix LCSC part number for ADC and part rotations
    [ADC.kicad_sch, interface_board.kicad_pcb]
2024-12-17 illumination_board_basic_RGBW: add hot surface warning and led polarity markings
    [Illumination_board.kicad_pcb, Illumination_board.kicad_sch]
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2024-12-17 sensor_board: add calculation file for buck led driver (AL8843)
    [AL8843-calculations.xls]
2024-12-17 sensor_board: reduce panellization to only horizontal due to JLCPCB server errors
2024-12-17 control_board: move led filtration capacitor behind coil (DNP)
    [control_board.kicad_pcb, led_driver.kicad_sch]
2024-12-17 control_board: change fan mosfets to DMC3071 with lower R_on
    [control_board.kicad_pcb, fan.kicad_sch]
2024-12-17 control_board: disable CC for TEC, add bypass resistor to TEC coild
    [control_board.kicad_pcb, motors.kicad_sch]
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2024-12-17 control_board: increase size of vias to 0.5/0.3 mm (from 0.4/0.3 mm)
    [control_board.kicad_pcb]
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2024-12-18 fluorometer_led: remove connector use only solder pads, add indexing notch
    [fluorometer_led.kicad_pcb, fluorometer_led.kicad_sch]
2024-12-18 control_board: change seconds thermistor input for 100k NTC
    [control_board.kicad_pcb, thermistors.kicad_sch]
2024-12-21 control_board: remove protection diodes from thermistor (distorts readings)
    [control_board.kicad_pcb, thermistors.kicad_sch]
2024-12-21 control_board: add LC filter to both sides of TEC
    [control_board.kicad_pcb, motors.kicad_sch]
2024-12-21 control_board: renumber all components in schematic and pcb
    [MCU.kicad_sch, can_interface.kicad_sch, control_board.kicad_pcb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]
2024-12-21 sensor_board: add LCSC part numbers to global sourcing components
    [ES_LED_Receiver.kicad_sch, TS_Emitter.kicad_sch, TS_Receiver.kicad_sch]
2024-12-21 sensor_board: mark thermistor diodes DNP to reduce temperature offset
    [Temperature_measurement.kicad_sch, sensor_board.kicad_pcb]
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2025-07-29 motor_shield_peristaltic: fix path to ignore manufacturing zip files
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2025-08-05 pump_board: fix component MPN names in BoM
    [MCU.kicad_sch, adc.kicad_sch, can_interface.kicad_sch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]
2025-08-05 pump_board: reduce left bottom lip of pcb, add panel tabs and config
    [MCU.kicad_sch, PCB_outline.dxf, PCB_placement.dxf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]
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2025-08-06 pump_board: swap pinout order for SATA connector and motor connectors
    [MCU.kicad_sch, can_interface.kicad_sch, debug.kicad_sch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]
2025-08-07 motor_shield_peristaltic: increase clearance of central hole
    [PCB_Outlines.dxf, motor_shield_peristaltic.kicad_pcb]
2025-08-07 motor_shield_peristaltic: update fabrication artefact for bigger clearance
    [motor_shield_peristaltic.kicad_pcb, motor_shield_peristaltic.step]
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2025-08-08 motor_shields: fix incorrectly named VCut layer in manufacturing files
    [motor_shield_airpump.kicad_pcb, motor_shield_airpump.step, motor_shield_peristaltic.kicad_pcb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]
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2026-01-06 pump_board: fix incorrect barrel jack connector
    [power.kicad_sch, pump_board.kicad_pcb, pump_board.step]
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2026-01-07 IL2_[N]UVNI[R]: fix incorrect power value in silkscreen
    [Illumination_board.kicad_pcb, Illumination_board.kicad_sch]
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
